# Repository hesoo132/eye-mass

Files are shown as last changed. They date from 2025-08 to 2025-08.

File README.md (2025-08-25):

# Eye-Mass Board  

## 🔎 Overview
**Eye-Mass** is a custom embedded hardware board designed for **real-time image processing and AI experimentation**.  
It integrates a camera (OV5640), external SDRAM, motor control, and communication interfaces to enable tasks such as **capturing and analyzing images of components inside a box**.

---

## 🔧 Hardware Features

| Component | Purpose |
|---|---|
| **Debug LED** | Visual feedback for board status and firmware debugging |
| **SDRAM** | Additional memory for buffering image data and running lightweight AI |
| **OV5640 Camera** | Captures images (e.g., counting SMD components inside a box) |
| **Motor Driver** | Moves the camera to capture the entire box view |
| **FDCAN** | High-speed, reliable communication with external modules |
| **USART** | Serial interface for debugging and logging |
| **Temperature Sensor**  | Monitors motor driver and board ambient temperature |
| **Current/Voltage Monitor** | Measures system power consumption and provides protection |

---

## 📸 Hardware Overview
| PCB Top | PCB Bottom |
|---|---|
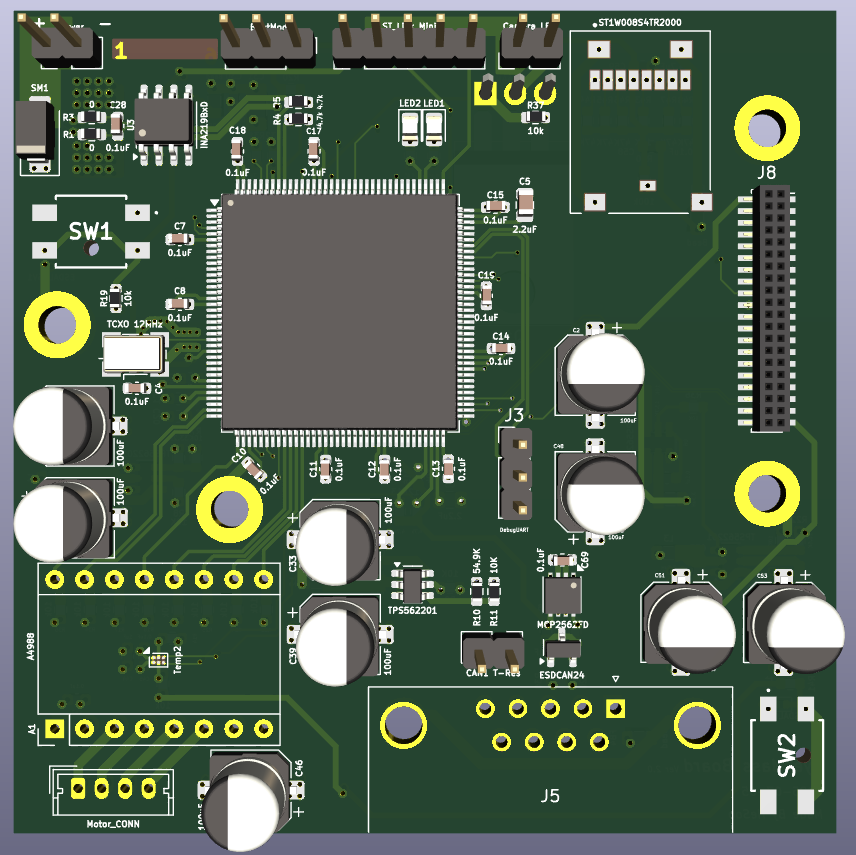
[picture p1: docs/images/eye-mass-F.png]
Top
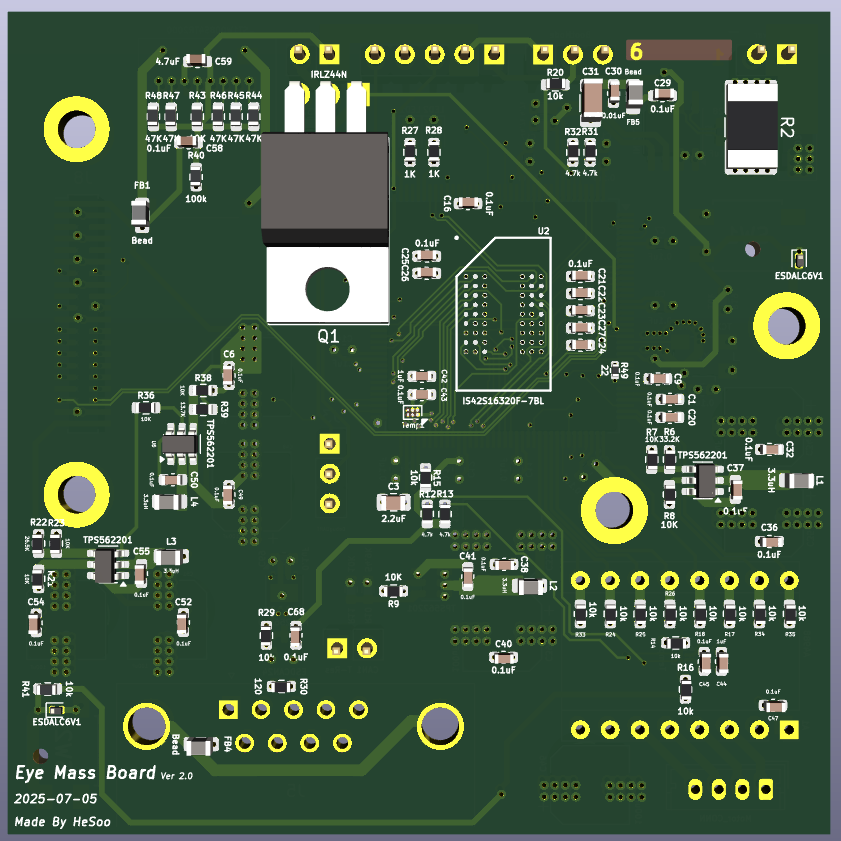
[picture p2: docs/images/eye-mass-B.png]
Bottom
|  |  |

---

## ✅ Current Status
- [x] Schematic design completed
- [x] PCB prototype (Rev. A) fabricated
- [x] SDRAM bring-up and validation
- [ ] Camera interface bring-up (OV5640)
- [x] Motor control & positioning test
- [x] Communication test (FDCAN, USART)
- [ ] Firmware integration (image capture + AI experimentation)

---

## 📑 References
- [STM32H7 Reference Manual](https://www.st.com/resource/en/reference_manual/dm00314099.pdf)  
- [OV5640 Camera Datasheet](https://www.arducam.com/downloads/datasheet/OV5640DS.pdf)

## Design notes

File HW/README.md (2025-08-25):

# Eye-Mass Hardware Design

## 🔎 Overview
The **Eye-Mass Board** is a custom embedded platform designed for **camera-based vision tasks and AI experimentation**.  
It integrates an OV5640 camera, external SDRAM, motor driver, and multiple debug/monitoring features.

---

## 📸 PCB Overview
| Top View | Bottom View |
|---|---|
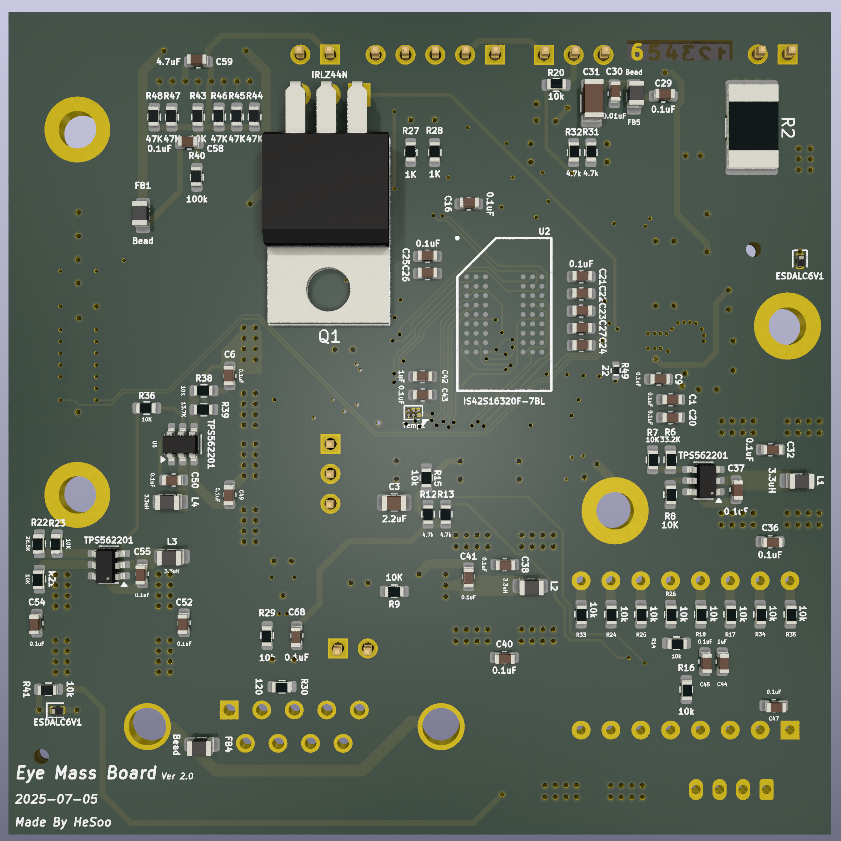
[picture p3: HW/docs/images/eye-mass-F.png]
Top
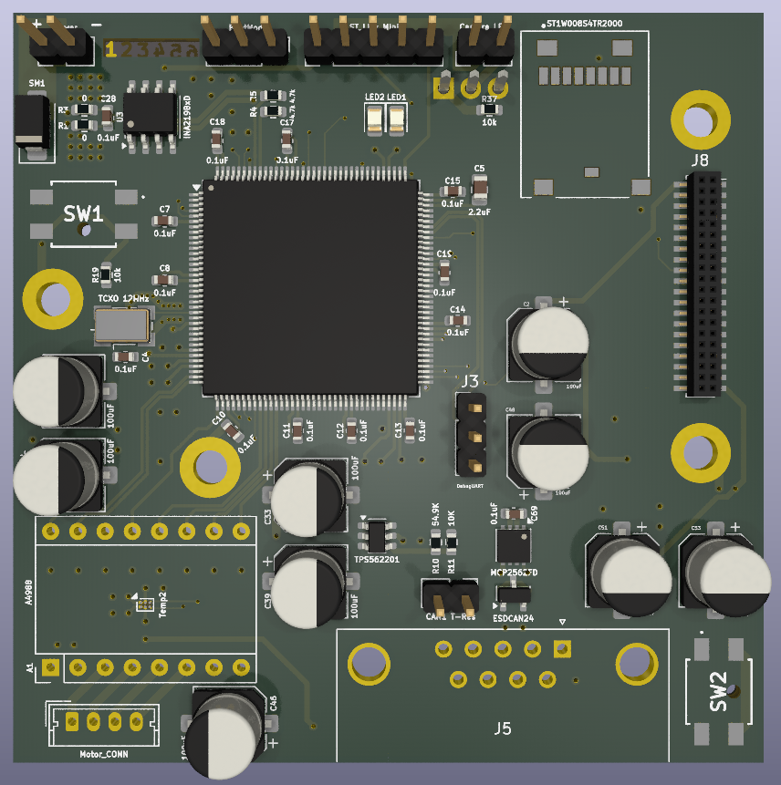
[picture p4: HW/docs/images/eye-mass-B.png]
Bottom
|  |  |

---

## 📑 Design Resources

- **Schematics**: [eye-mass.pdf](eye-mass.pdf) (PDF for quick view)
    
---

## 🔧 Key Hardware Notes
- **EDA Tool**: KiCad 9.0  
- **PCB Stackup**: 6-layer, impedance-controlled for high-speed (DCMI, FDCAN)  
- **Memory**: External SDRAM for real-time image buffering + AI workloads  
- **Camera**: OV5640 with DCMI interface for capturing and analysis  
- **Motor Driver**: Enables camera positioning to capture full target area  
- **Debugging**: LEDs + USART interface  
- **Monitoring**: Temperature and current/voltage sensing  

---

## 🧩 Schematic Highlights

### 1) MCU — STM32H723ZGT6
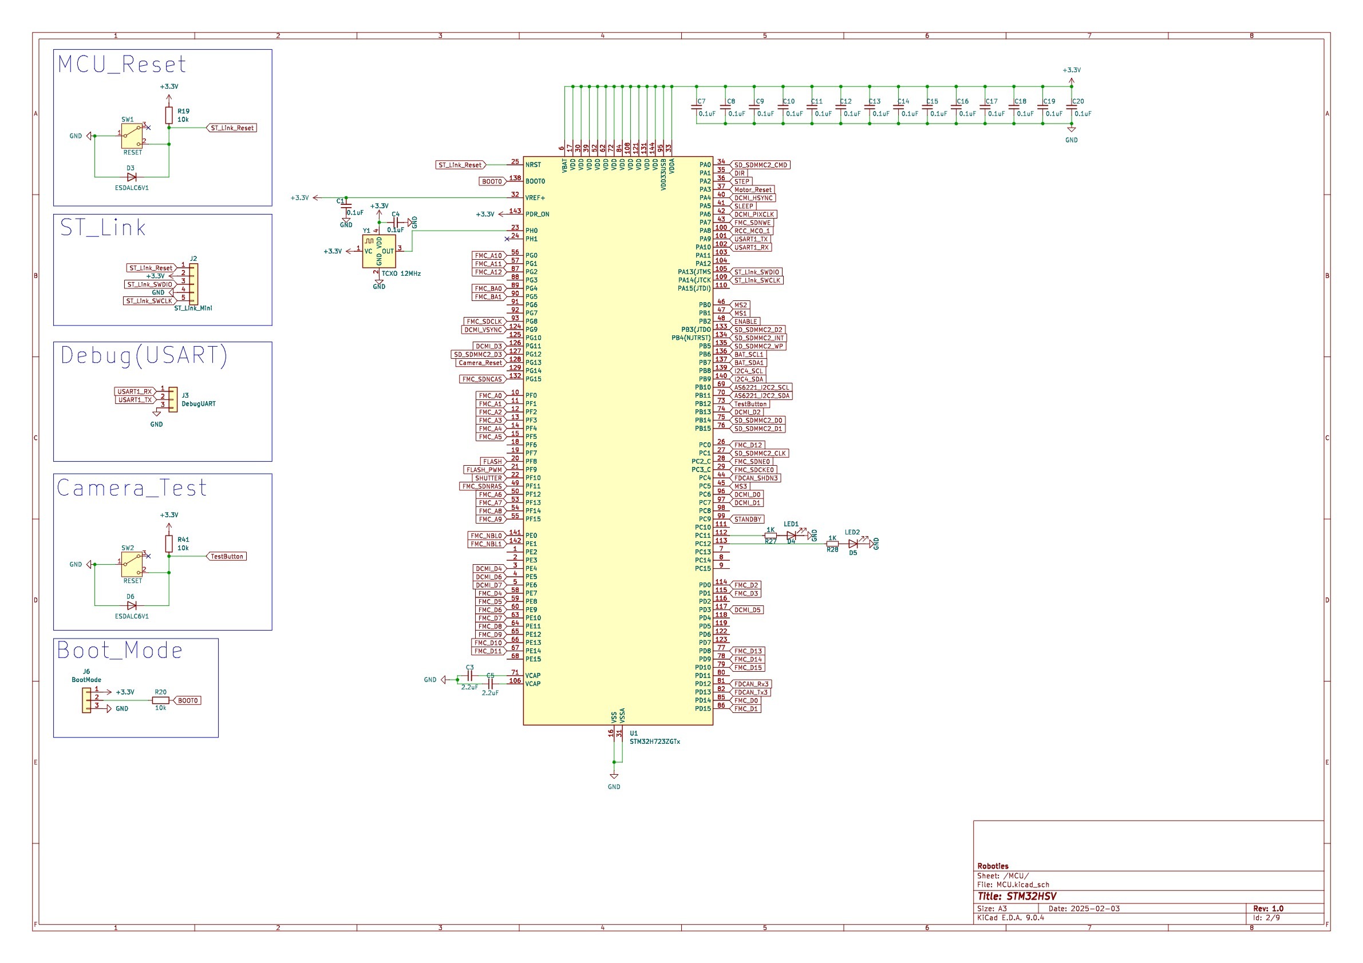
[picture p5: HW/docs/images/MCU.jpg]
MCU

- **Device**: STM32H723ZGT6 
- **Connections**: Debug UART, **ST-Link Mini** (SWD), boot-mode pins, GPIO banks **PA/PB/PC/PD/PE/PF/PG**, external clock **TCXO 12 MHz**, reset circuit  
- **Purpose**: Central control with dedicated debug/boot paths and ample I/O for peripherals

### 2) SDRAM — IS42S16320F-7BL
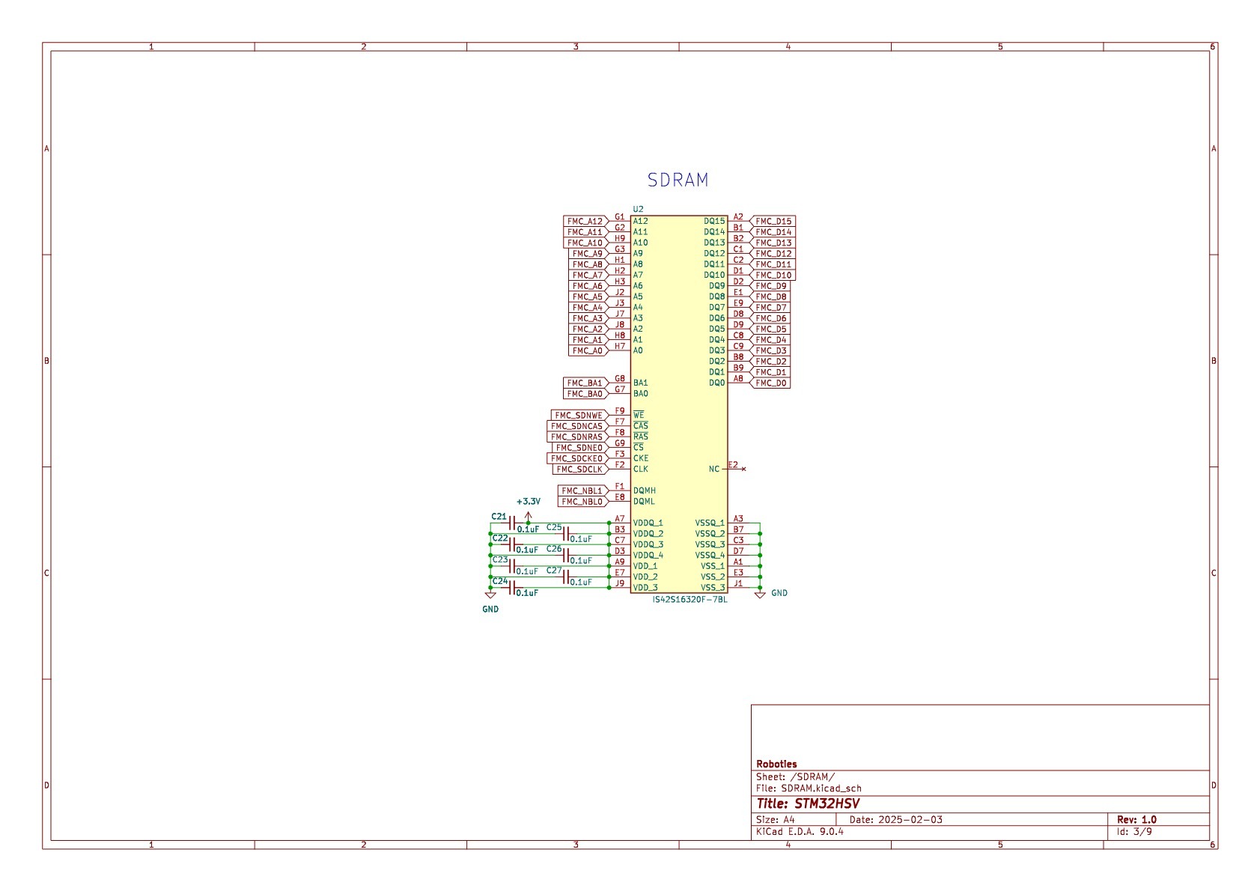
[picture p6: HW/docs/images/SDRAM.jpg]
SDRAM

- **Device**: IS42S16320F-7BL  
- **Interface**: **FMC** — DQ0–DQ15, A0–A12, BA0–BA1, **SDNWE/SDNCAS/SDNRAS/SDNE0/SDCKE0/SDCLK**, NBL0/NBL1  
- **Purpose**: External memory to expand capacity for image buffering and lightweight AI execution

### 3) Power
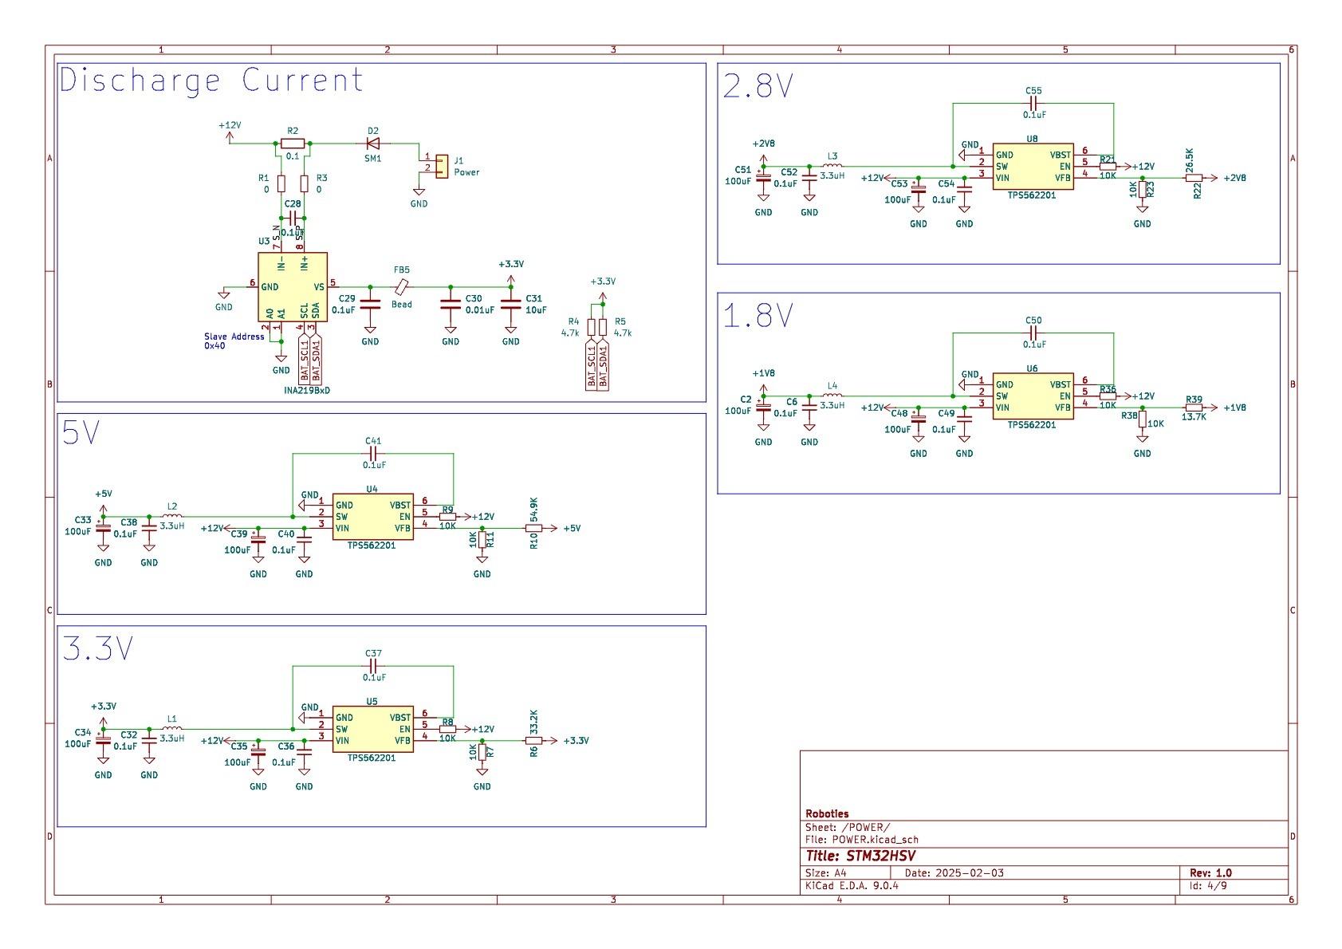
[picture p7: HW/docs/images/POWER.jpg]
Power

- **Key ICs**: **INA219BxD** (current/voltage monitor), **TPS562201** (buck converter)  
- **Rails**: From **+12 V** input to **+5 V / +3.3 V / +2.8 V / +1.8 V**  
- **Purpose**: Stable multi-rail supply with inline power telemetry for easier power management

### 4) Camera — OV5640
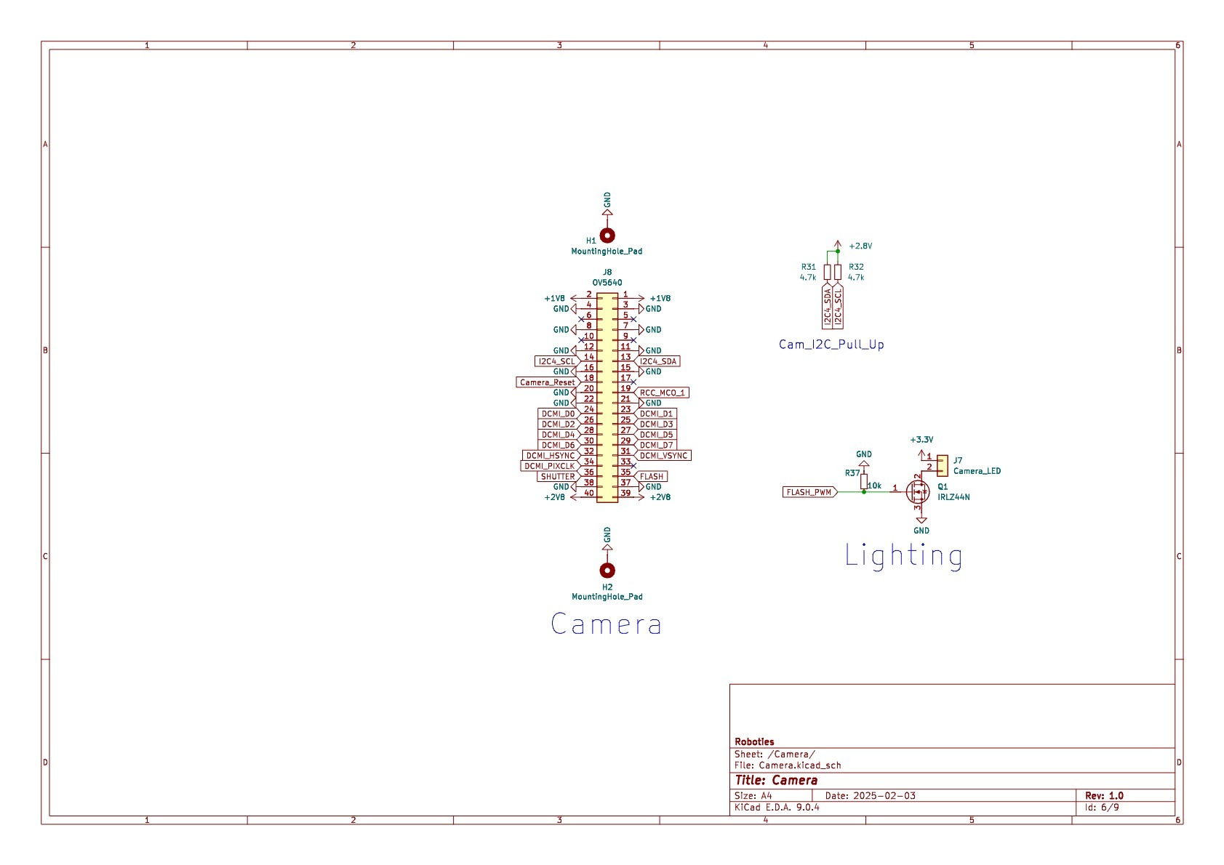
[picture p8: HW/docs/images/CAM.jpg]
Camera

- **Sensor**: **OV5640**  
- **Interface**: **DCMI** (D0–D7, HSYNC, VSYNC, PIXCLK) + **I²C4** (SCL, SDA)  
- **Power & Control**: **+1.8 V / +2.8 V / +3.3 V** rails, LED control (**Camera_LED**, **FLASH**, **FLASH_PWM**)  
- **Use Case**: Capturing images for tasks like **counting SMD components inside a box**

### 5) FDCAN
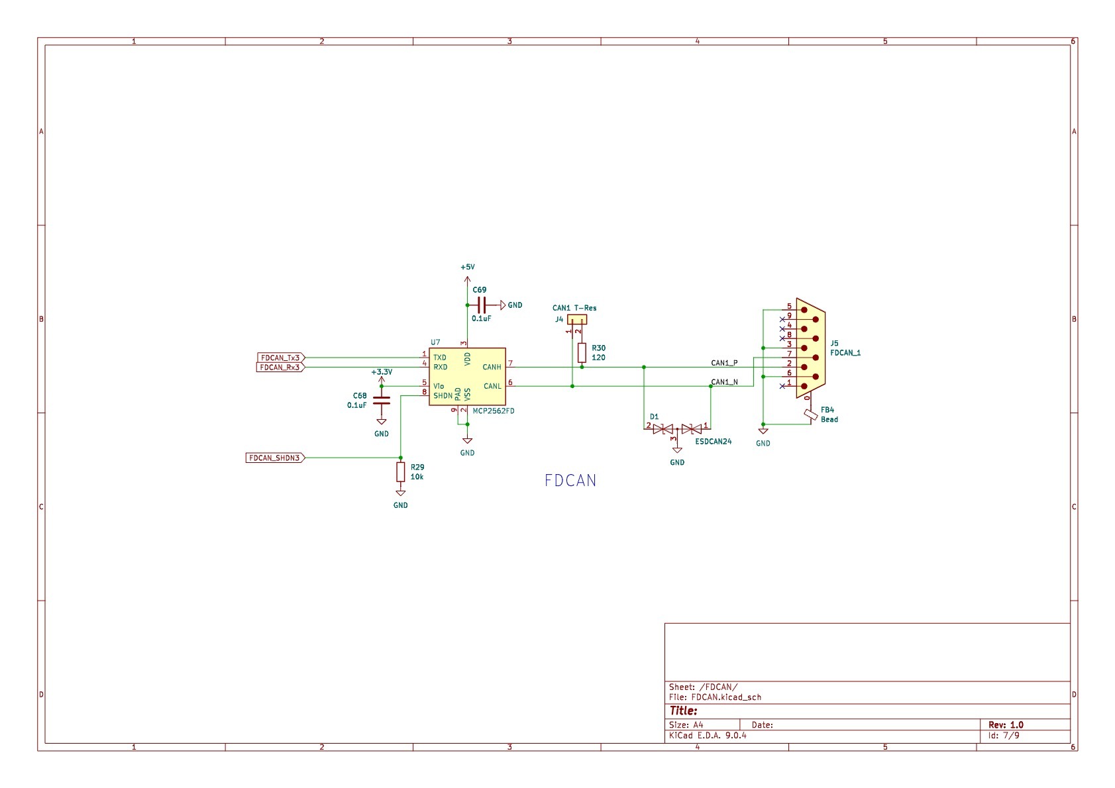
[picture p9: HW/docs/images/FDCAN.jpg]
FDCAN

- **Transceiver**: **MCP2562FD**  
- **Connections**: MCU **FDCAN_Tx3 / FDCAN_Rx3** ↔ bus **CANH/CANL**; includes **120 Ω** termination  
- **Purpose**: Robust CAN communication to external modules/systems

### 6) Temperature — AS6221 ×2
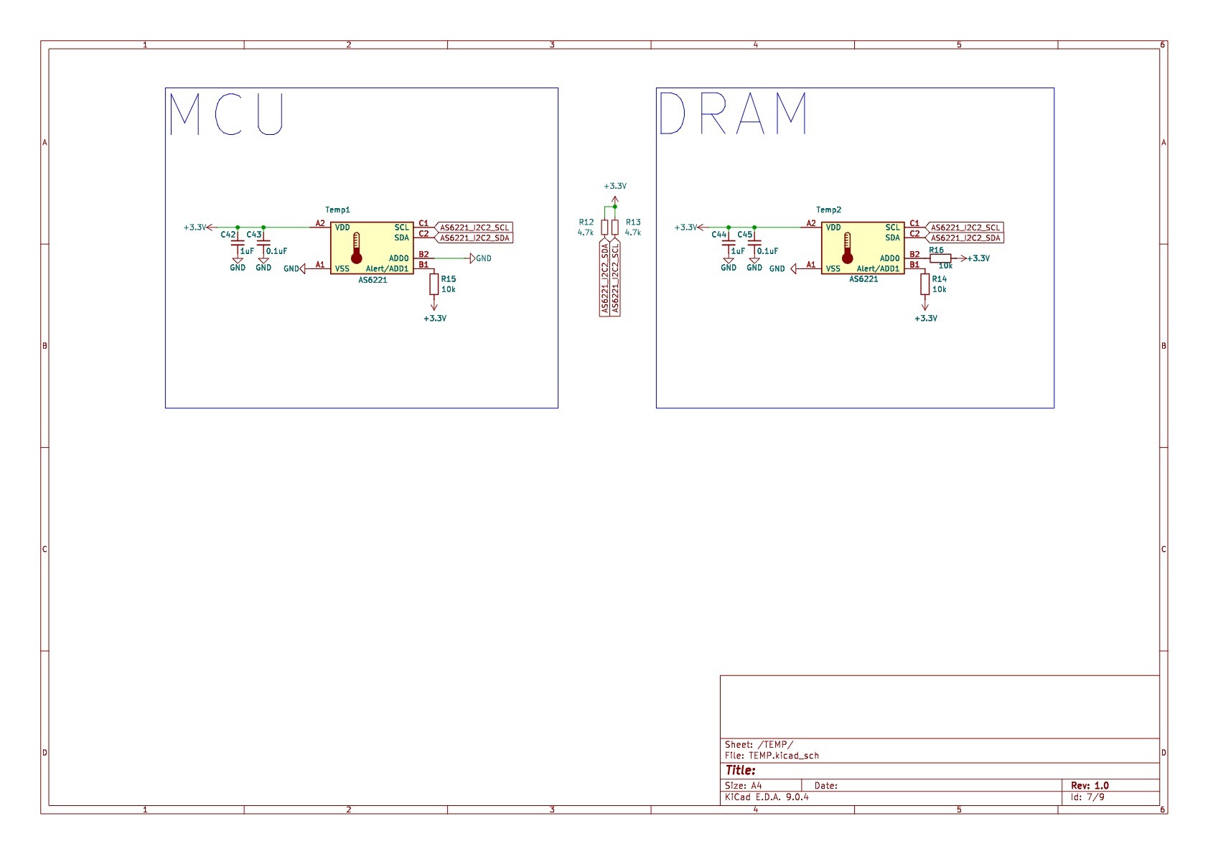
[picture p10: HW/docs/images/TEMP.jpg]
Temp

- **Sensors**: **AS6221** ×2  
- **Interface**: **I²C2** (SCL, SDA)  
- **Purpose**: Dual-point temperature monitoring (e.g., motor driver and board ambient)

### 7) Motor Driver — A4988
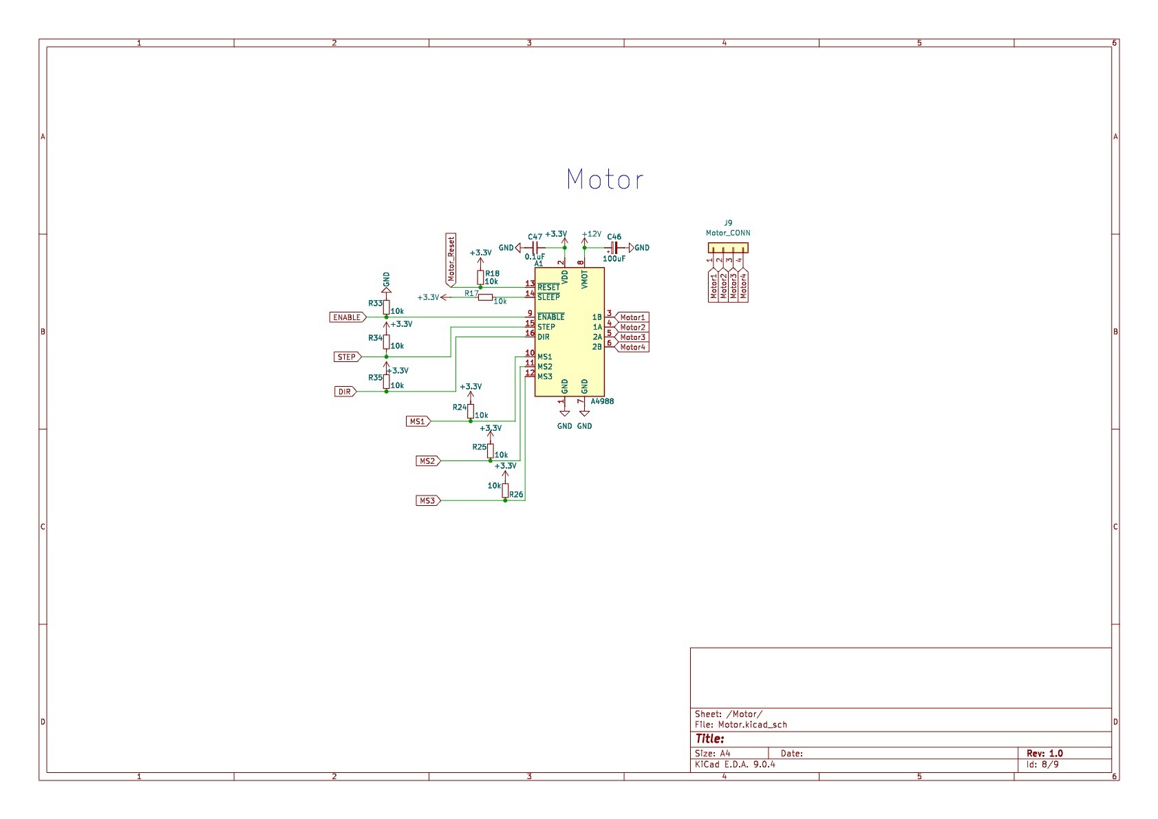
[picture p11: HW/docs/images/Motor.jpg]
Motor

- **Driver**: **A4988**  
- **Signals**: **STEP, DIR, ENABLE, MS1, MS2, MS3**; outputs **1A/1B/2A/2B**  
- **Purpose**: Stepper control with microstepping configuration for camera positioning

### 8) microSD — SDMMC2
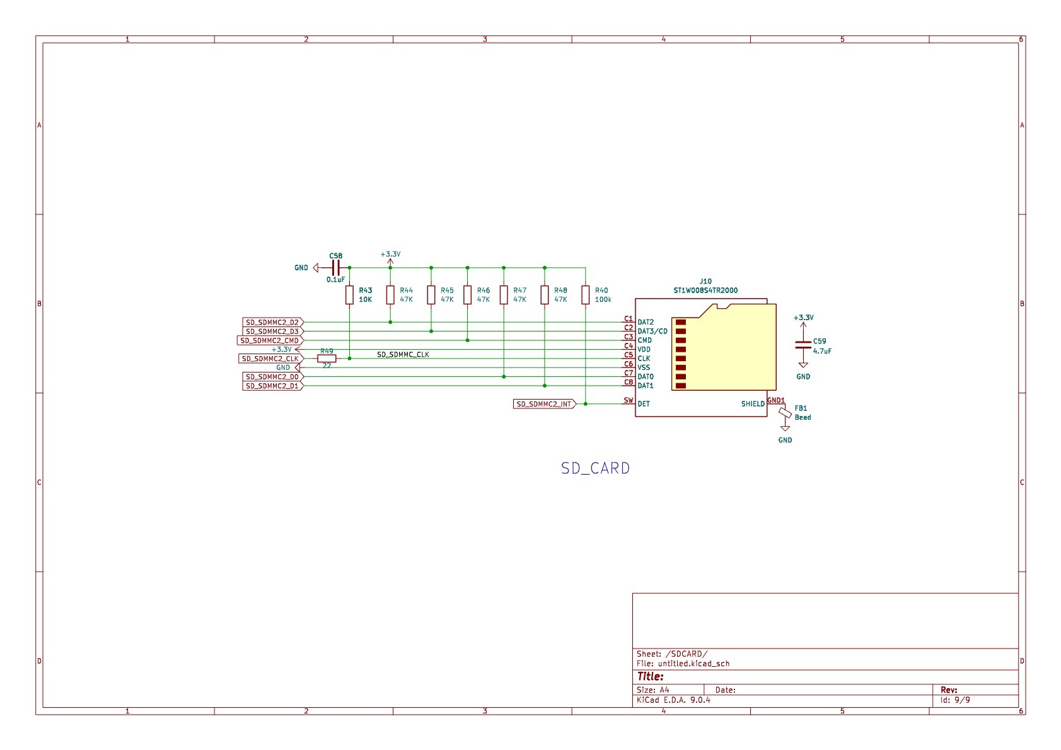
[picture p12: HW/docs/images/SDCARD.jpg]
SD

- **Interface**: **SDMMC2** — D0–D3, CMD, CLK, INT  
- **Purpose**: Removable storage for images and logs

---

## ✅ Progress
- [x] Schematics completed  
- [x] PCB prototype (Rev. A) fabricated  
- [x] SDRAM bring-up (partial validation ongoing)  
- [ ] Camera interface bring-up (OV5640)  
- [x] Motor driver test & positioning control  
- [x] Communication tests (FDCAN / USART)

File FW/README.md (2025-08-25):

# 📷 STM32H723ZGT6 – Vision & Control Firmware

## 🔎 Overview
This firmware is developed for the **STM32H723ZGT6** based embedded platform.  
The system is designed to capture images of **SMD components inside a box** and perform counting with camera + AI (WIP).  
It integrates **external SDRAM, motor driver, SD card logging, temperature/current sensors, and FDCAN communication**.

---

## ⚙️ Features

- ✅ **SD Card (SDMMC2)**  
  - File creation & logging tested successfully  
  - Stores captured data and sensor logs

- ✅ **SDRAM (IS42S16320F-6BLI)**  
  - JEDEC init sequence implemented  
  - Full memory write/read test completed

- ✅ **Motor Control (A4988)**  
  - Supports speed & distance control  
  - Verified positioning logic for camera movement

- ✅ **Temperature Sensor (AS6221)**  
  - I²C2 interface  
  - Accurate ambient + board temp reading

- ✅ **Current/Voltage Monitor (INA219B)**  
  - I²C3 interface  
  - Real-time bus voltage & shunt current measurement

- ✅ **FDCAN Communication**  
  - I²C4 interface 
  - Protocol layer implemented  
  - Verified with external CAN nodes

- ⏳ **Camera (OV5640 + DCMI DMA)**  
  - Basic bring-up in progress  
  - SDRAM frame buffer prepared  
  - AI-based SMD counting pipeline: **Planned**

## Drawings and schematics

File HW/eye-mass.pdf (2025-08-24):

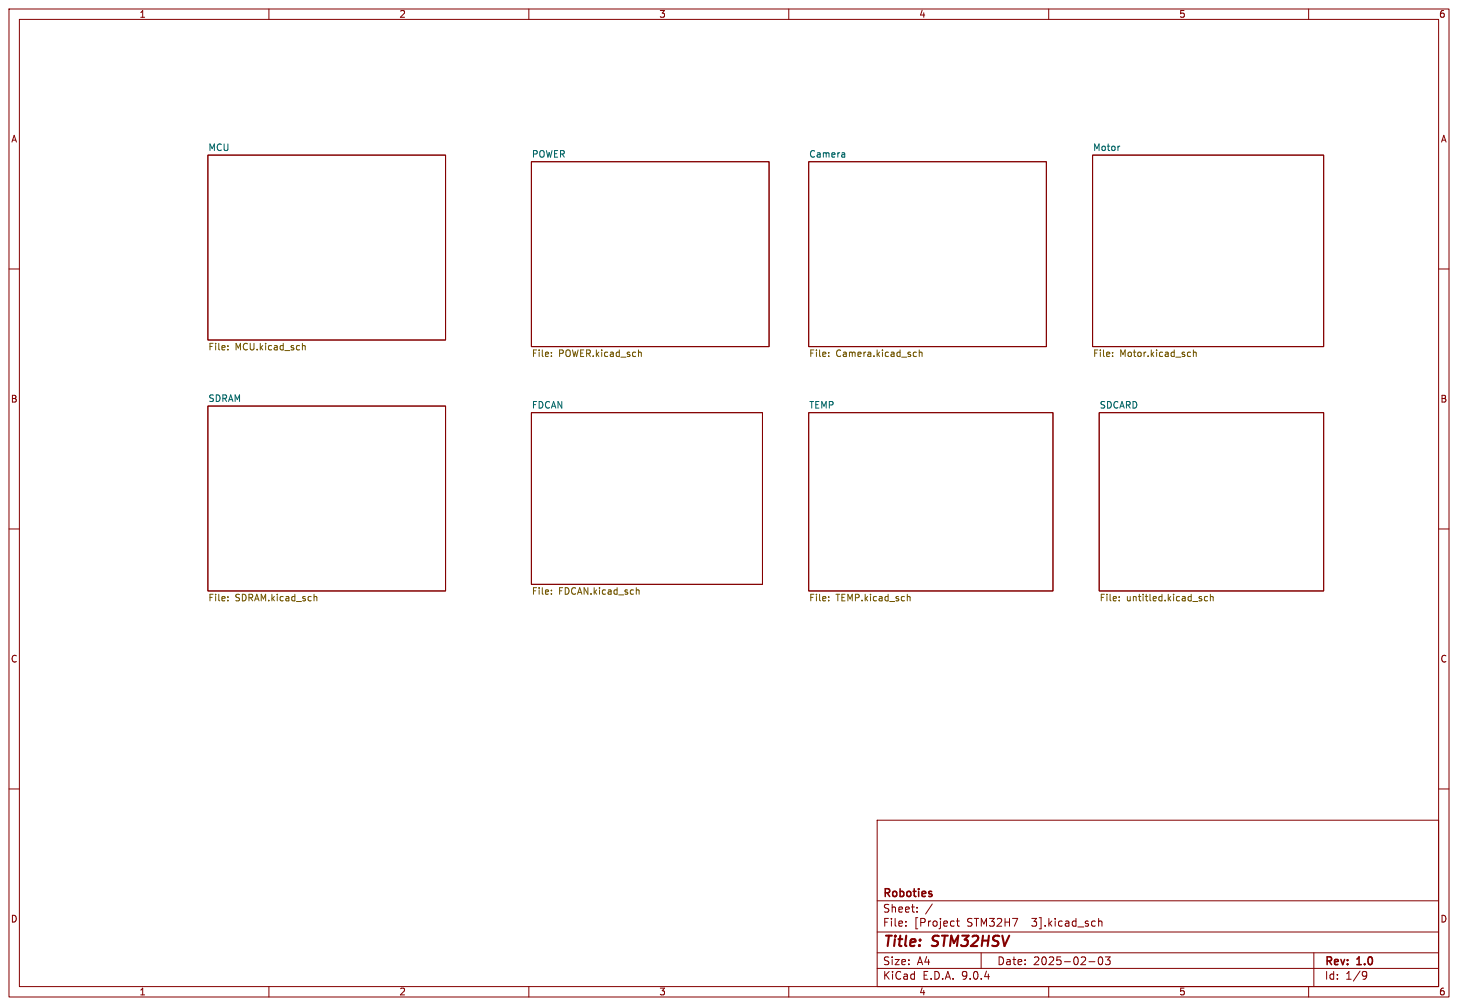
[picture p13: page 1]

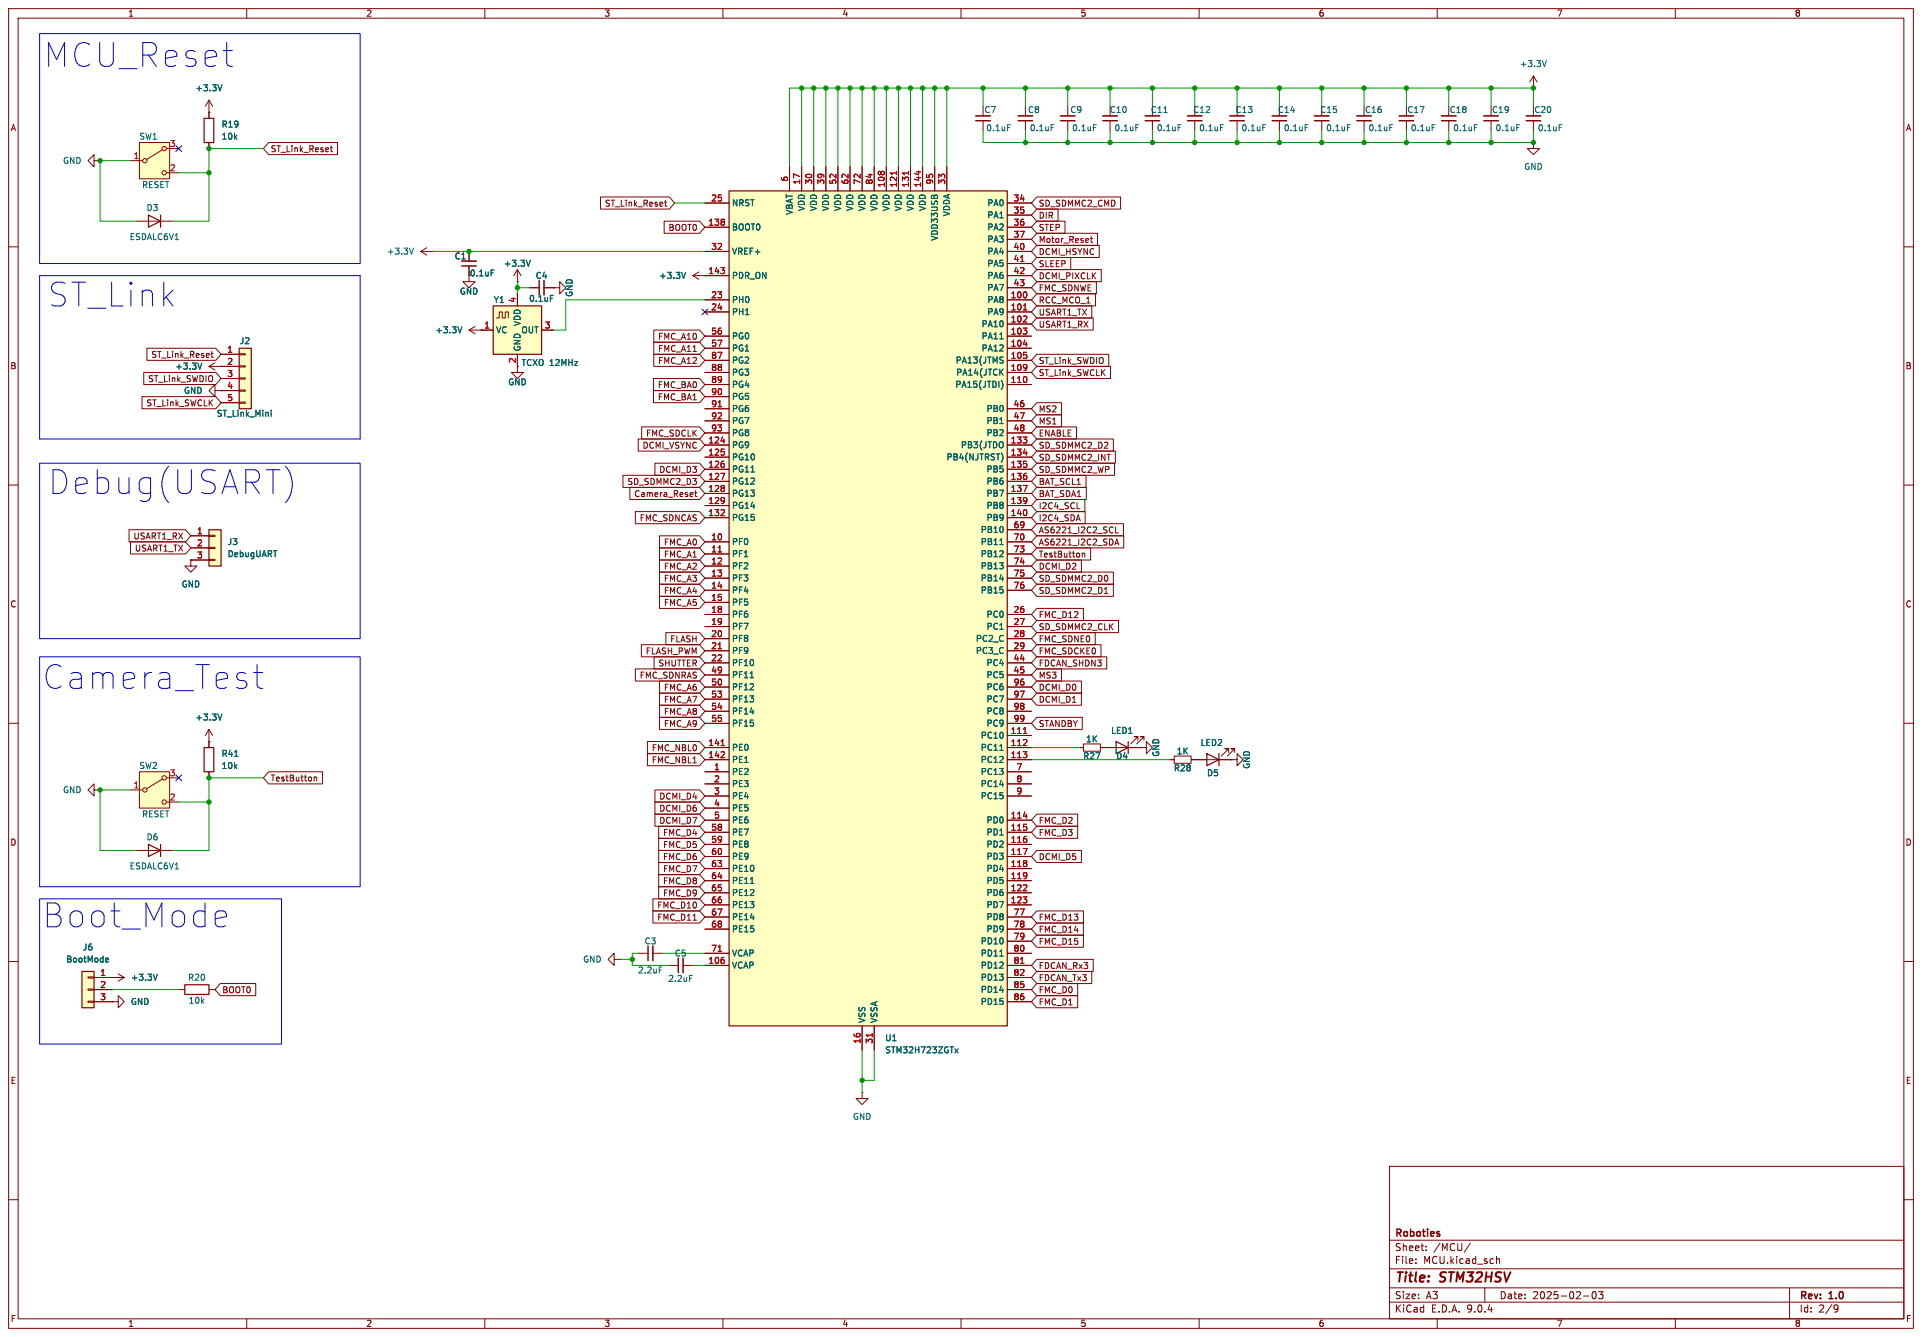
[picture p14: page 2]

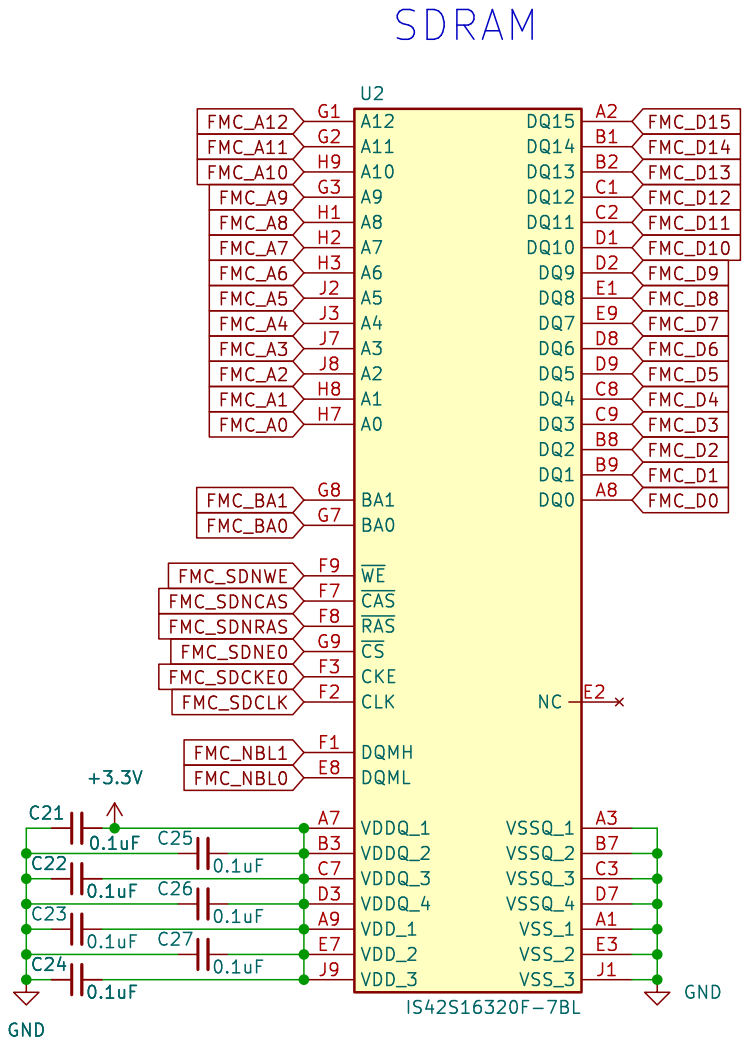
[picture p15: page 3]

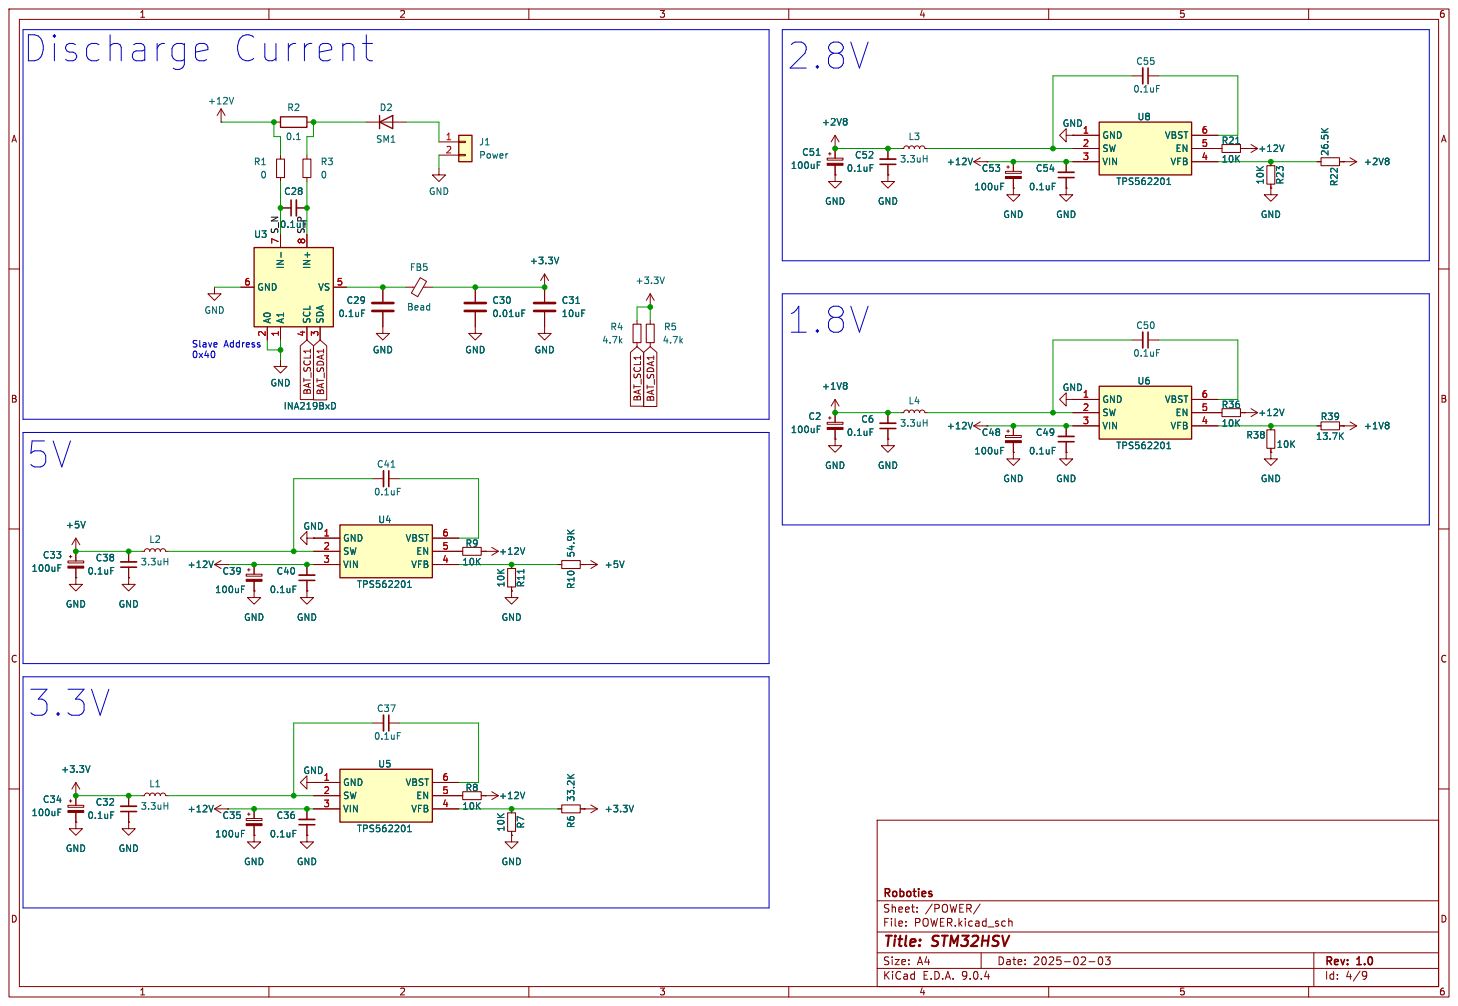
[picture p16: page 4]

8 IN- 7 VS 5 GND 6 SDA

File: POWER.kicad_sch Sheet: /POWER/ Roboties C40

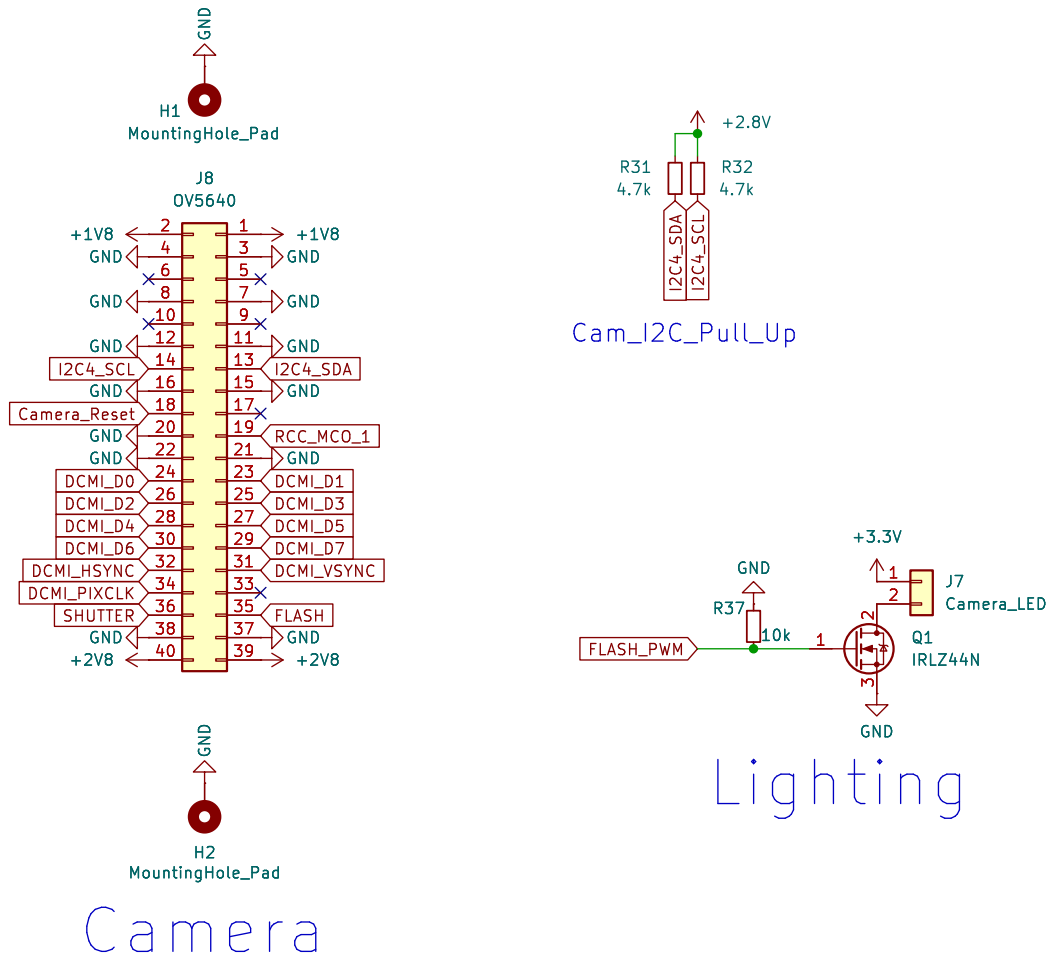
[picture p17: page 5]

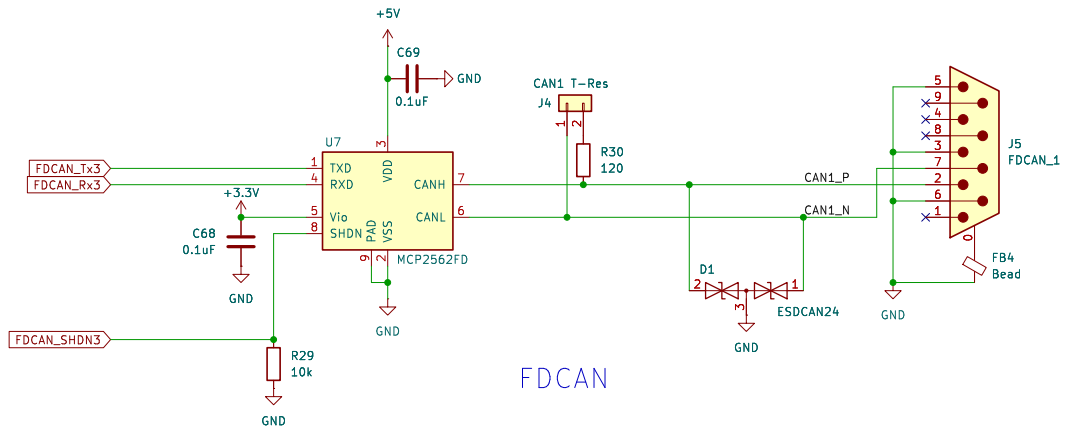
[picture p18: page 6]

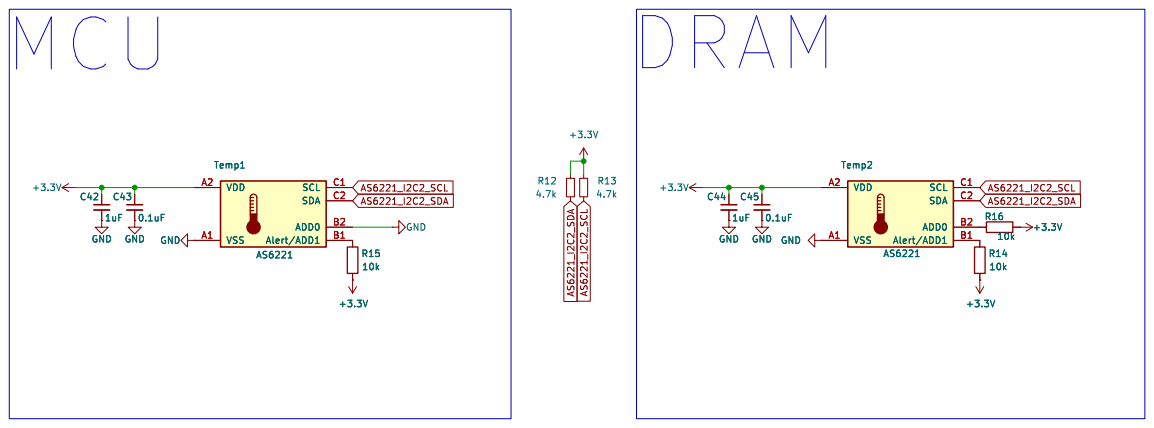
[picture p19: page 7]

Id: 7/9 Title: File: TEMP.kicad_sch Sheet: /TEMP/

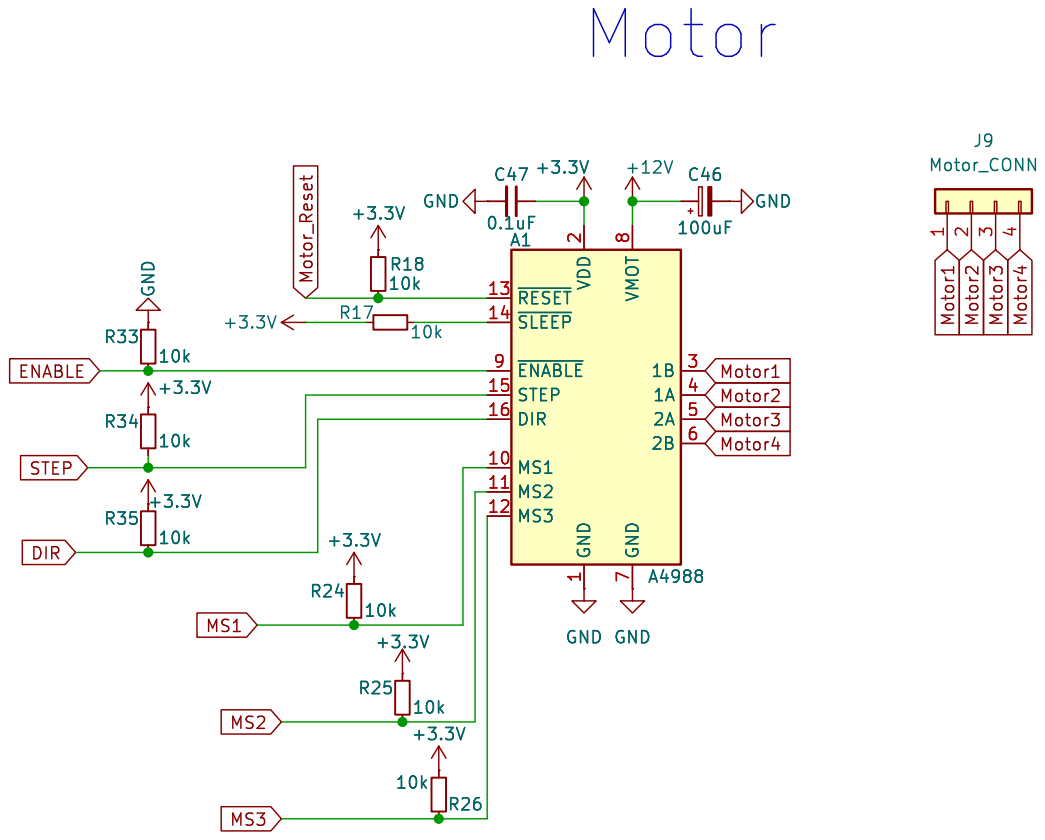
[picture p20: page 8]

Id: 8/9 Title: File: Motor.kicad_sch Sheet: /Motor/

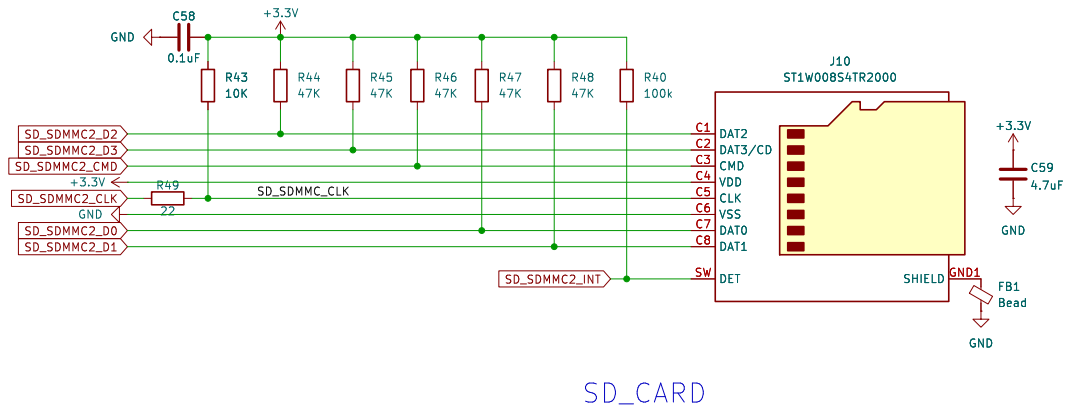
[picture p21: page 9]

Id: 9/9 Title: File: untitled.kicad_sch Sheet: /SDCARD/

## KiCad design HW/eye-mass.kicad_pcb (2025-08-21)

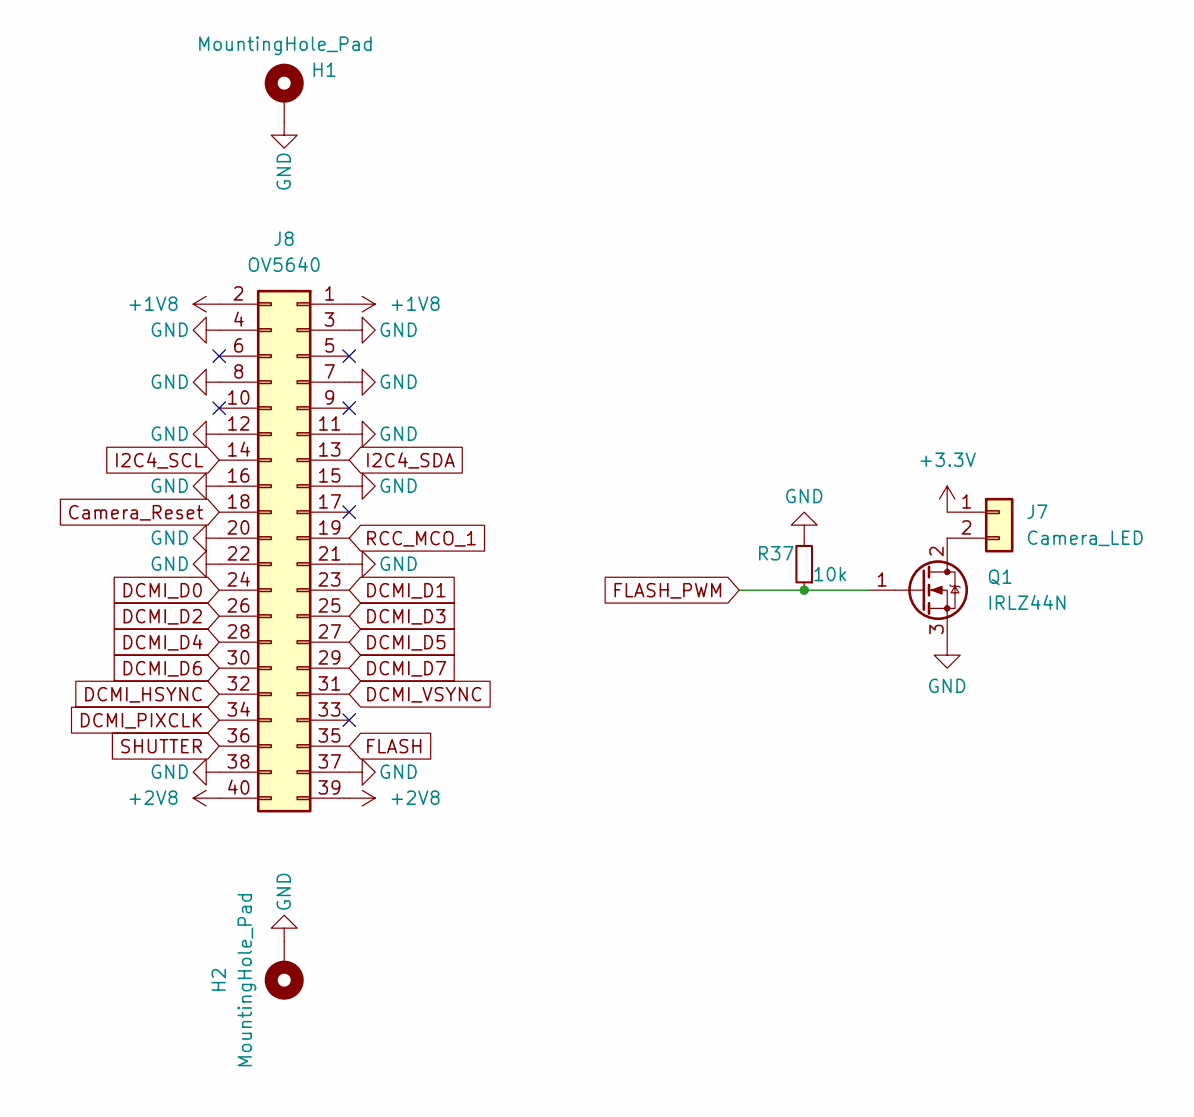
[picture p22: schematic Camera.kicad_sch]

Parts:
H1, H2: MountingHole_Pad; MountingHole_3.2mm_M3_DIN965_Pad
J7: Camera_LED; PinHeader_1x02_P2.54mm_Vertical
J8: OV5640; PinSocket_2x20_P1.00mm_Vertical_SMD
Q1: IRLZ44N; TO-220-3_Horizontal_TabDown
R37: 10k; R_0603_1608Metric

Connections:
+1V8: J8.1, J8.2; also elsewhere on the board
+2V8: J8.39, J8.40; also elsewhere on the board
+3.3V: J7.1; also elsewhere on the board
Camera_Reset: J8.18; also elsewhere on the board
DCMI_D0: J8.24; also elsewhere on the board
DCMI_D1: J8.23; also elsewhere on the board
DCMI_D2: J8.26; also elsewhere on the board
DCMI_D3: J8.25; also elsewhere on the board
DCMI_D4: J8.28; also elsewhere on the board
DCMI_D5: J8.27; also elsewhere on the board
DCMI_D6: J8.30; also elsewhere on the board
DCMI_D7: J8.29; also elsewhere on the board
DCMI_HSYNC: J8.32; also elsewhere on the board
DCMI_PIXCLK: J8.34; also elsewhere on the board
DCMI_VSYNC: J8.31; also elsewhere on the board
FLASH: J8.35; also elsewhere on the board
FLASH_PWM: Q1.1 (G), R37.1; also elsewhere on the board
GND: H1.1, H2.1, J8.3, J8.4, J8.7, J8.8, J8.11, J8.12, J8.15, J8.16, J8.20, J8.21, J8.22, J8.37, J8.38, Q1.3 (S), R37.2; also elsewhere on the board
I2C4_SCL: J8.14; also elsewhere on the board
I2C4_SDA: J8.13; also elsewhere on the board
unnamed: J7.2, Q1.2 (D)
RCC_MCO_1: J8.19; also elsewhere on the board
SHUTTER: J8.36; also elsewhere on the board

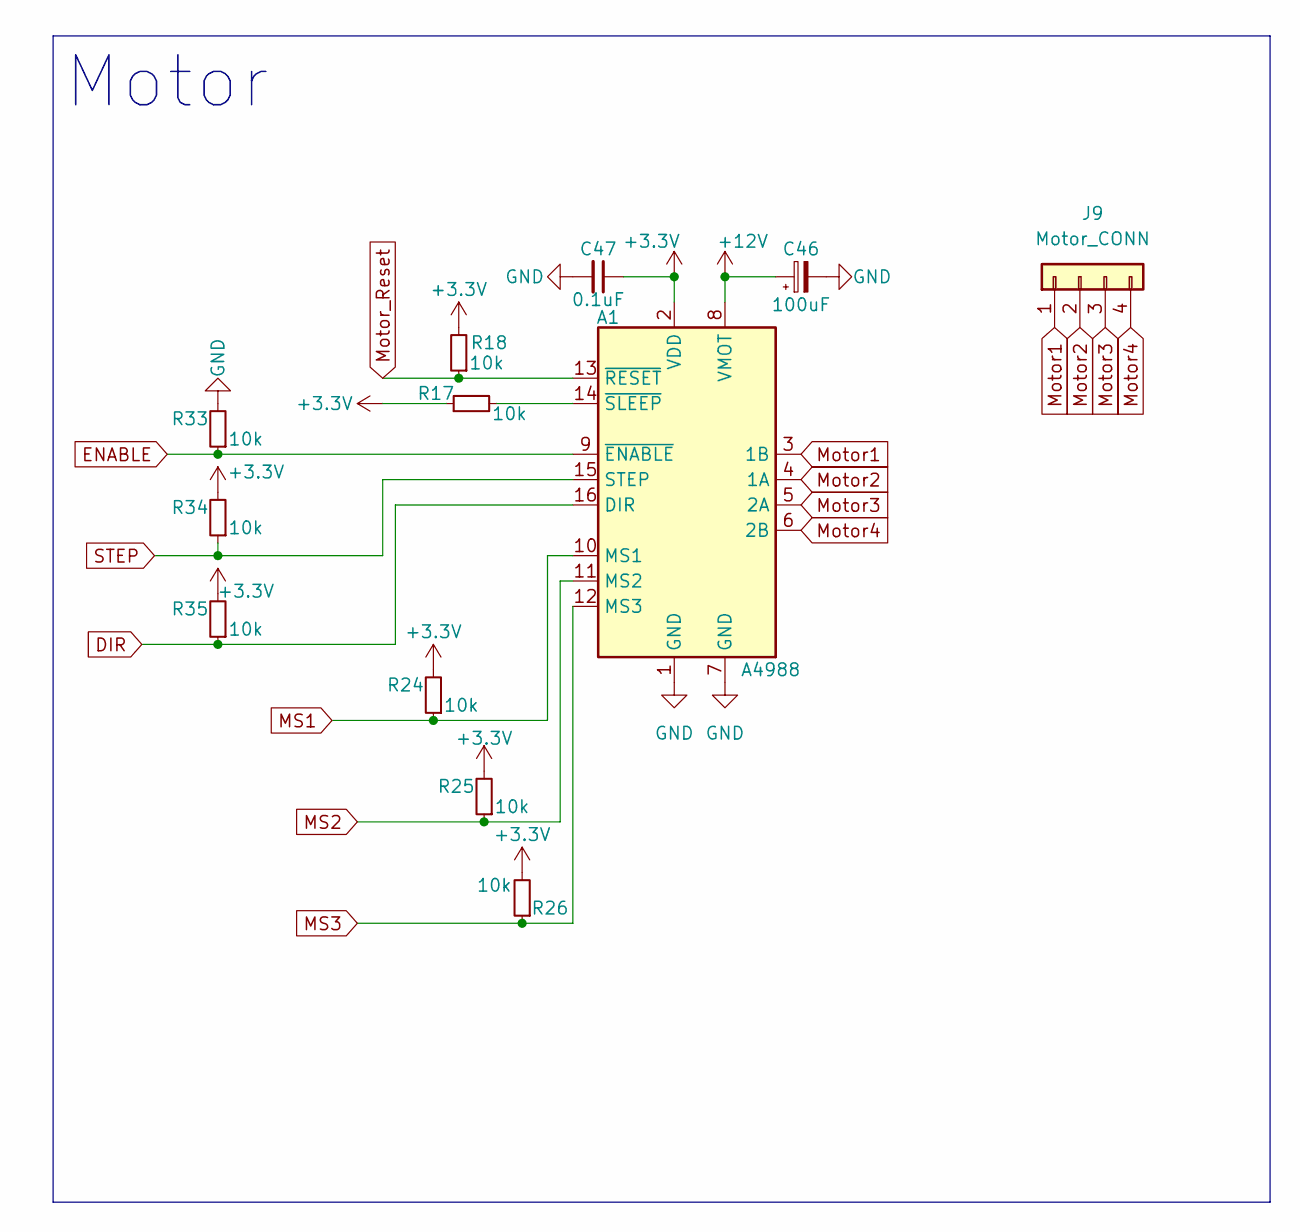
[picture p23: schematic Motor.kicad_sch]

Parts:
A1: A4988; Pololu_Breakout-16_15.2x20.3mm
C46: 100uF; CP_Elec_6.3x5.9
C47: 0.1uF; C_0603_1608Metric
J9: Motor_CONN; Molex_Micro-Latch_53253-0470_1x04_P2.00mm_Vertical
R17, R18, R24, R25, R26, R33, R34, R35: 10k; R_0603_1608Metric

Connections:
+3.3V: A1.2 (VDD), C47.1, R17.1, R18.2, R24.2, R25.2, R26.2, R34.2, R35.2; also elsewhere on the board
+12V: A1.8 (VMOT), C46.1; also elsewhere on the board
DIR: A1.16 (DIR), R35.1; also elsewhere on the board
ENABLE: A1.9 (~ENABLE), R33.1; also elsewhere on the board
GND: A1.1 (GND), A1.7 (GND), C46.2, C47.2, R33.2; also elsewhere on the board
MS1: A1.10 (MS1), R24.1; also elsewhere on the board
MS2: A1.11 (MS2), R25.1; also elsewhere on the board
MS3: A1.12 (MS3), R26.1; also elsewhere on the board
Motor1: A1.3 (1B), J9.1
Motor2: A1.4 (1A), J9.2
Motor3: A1.5 (2A), J9.3
Motor4: A1.6 (2B), J9.4
Motor_Reset: A1.13 (~RESET), R18.1; also elsewhere on the board
unnamed: A1.14 (~SLEEP), R17.2
STEP: A1.15 (STEP), R34.1; also elsewhere on the board

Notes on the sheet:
Motor

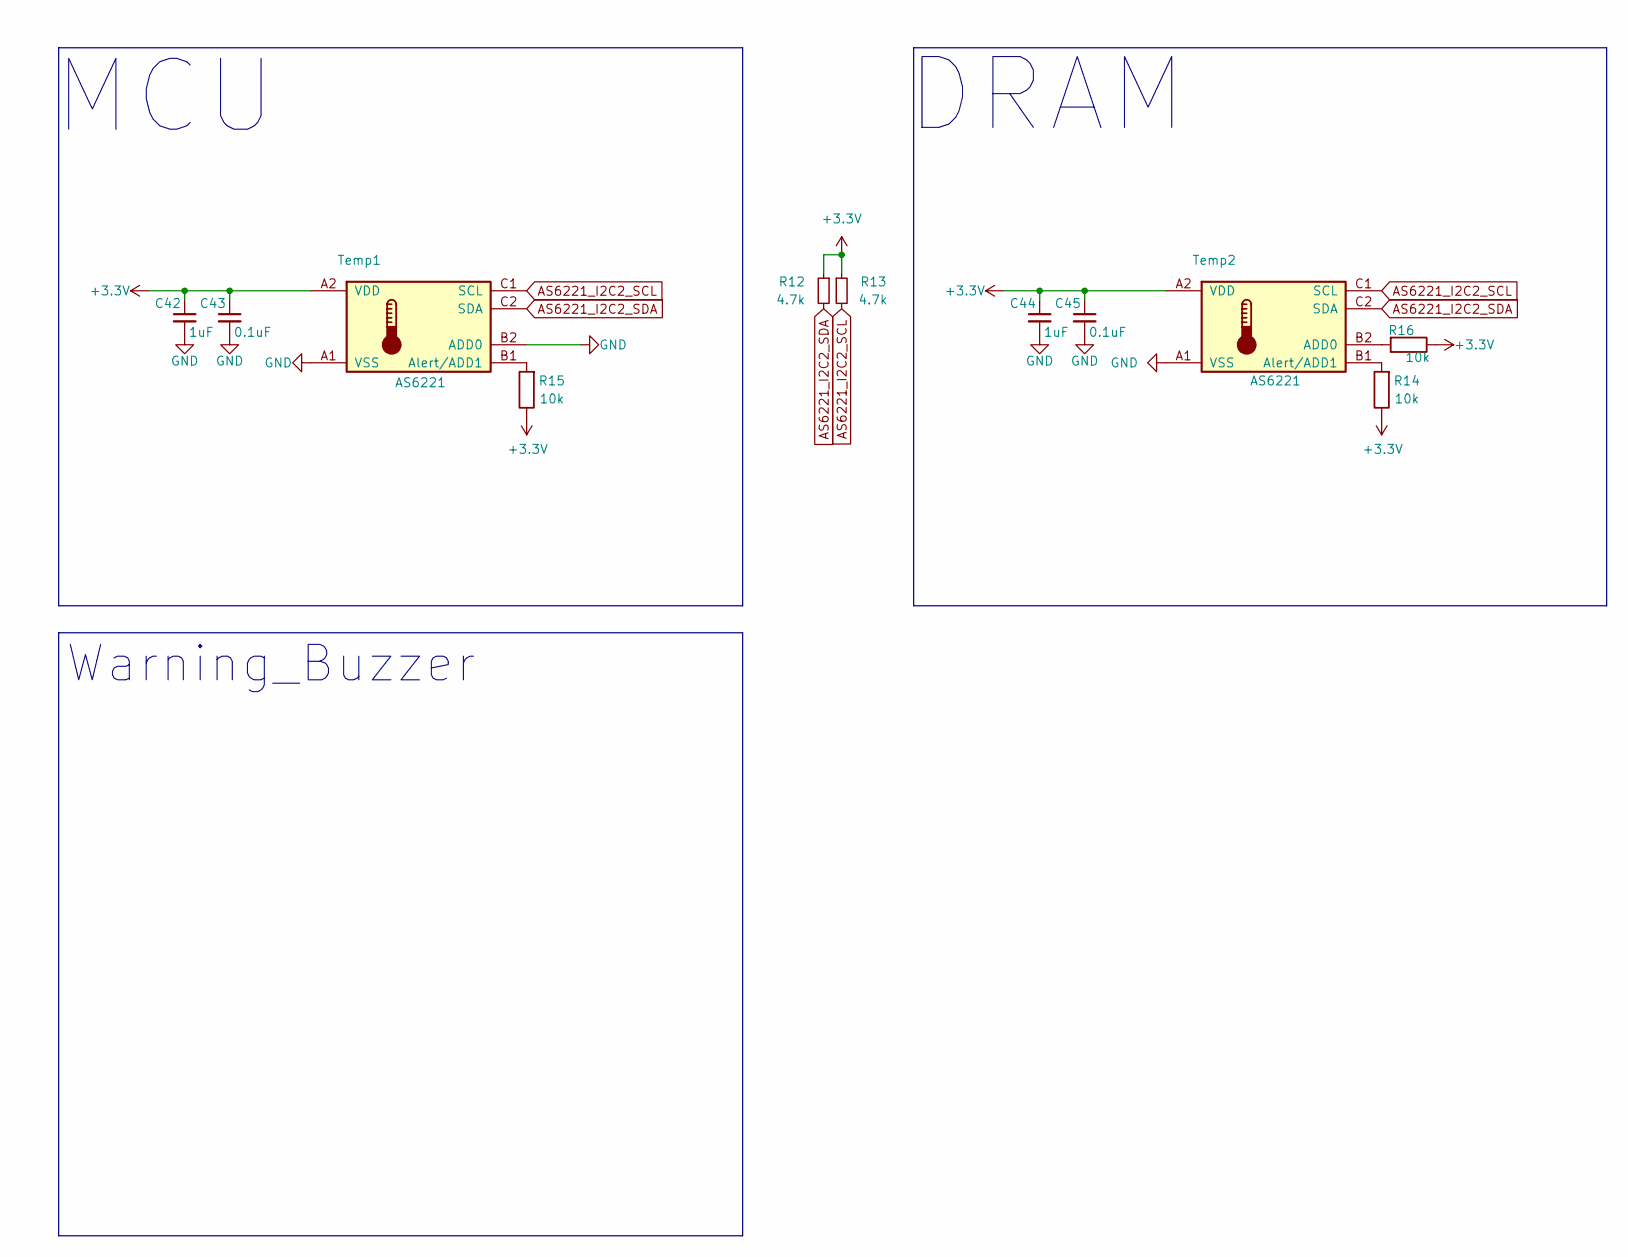
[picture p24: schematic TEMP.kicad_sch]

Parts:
C42, C44: 1uF; C_0603_1608Metric
C43, C45: 0.1uF; C_0603_1608Metric
R12, R13: 4.7k; R_0603_1608Metric
R14, R15, R16: 10k; R_0603_1608Metric
Temp1, Temp2: AS6221; WLCSP-6_1.4x1.0mm_P0.4mm

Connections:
+3.3V: C42.1, C43.1, C44.1, C45.1, R12.1, R13.1, R14.1, R15.1, R16.1, Temp1.A2 (VDD), Temp2.A2 (VDD); also elsewhere on the board
AS6221_I2C2_SCL: R13.2, Temp1.C1 (SCL), Temp2.C1 (SCL); also elsewhere on the board
AS6221_I2C2_SDA: R12.2, Temp1.C2 (SDA), Temp2.C2 (SDA); also elsewhere on the board
GND: C42.2, C43.2, C44.2, C45.2, Temp1.A1 (VSS), Temp1.B2 (ADD0), Temp2.A1 (VSS); also elsewhere on the board
unnamed: R15.2, Temp1.B1 (Alert/ADD1)
unnamed: R16.2, Temp2.B2 (ADD0)
unnamed: R14.2, Temp2.B1 (Alert/ADD1)

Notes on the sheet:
Warning_Buzzer
MCU
DRAM

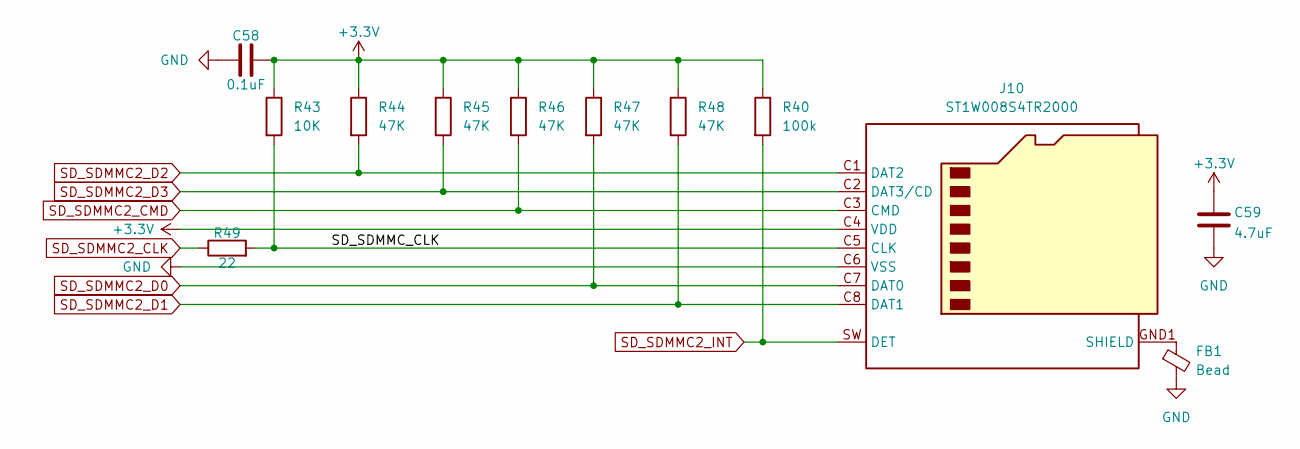
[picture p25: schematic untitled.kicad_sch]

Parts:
C58: 0.1uF; C_0603_1608Metric
C59: 4.7uF; C_0603_1608Metric
FB1: Bead; L_0805_2012Metric
J10: ST1W008S4TR2000; JAE_ST1W008S4TR2000
R40: 100k; R_0603_1608Metric
R43: 10K; R_0603_1608Metric
R44, R45, R46, R47, R48: 47K; R_0603_1608Metric
R49: 22; R_0402_1005Metric

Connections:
+3.3V: C58.2, C59.2, J10.C4 (VDD), R40.1, R43.1, R44.1, R45.1, R46.1, R47.1, R48.1; also elsewhere on the board
/SDCARD/SD_SDMMC_CLK: J10.C5 (CLK), R43.2, R49.2
GND: C58.1, C59.1, FB1.2, J10.C6 (VSS); also elsewhere on the board
unnamed: FB1.1, J10.GND1 (SHIELD), J10.GND2 (SHIELD), J10.GND3 (SHIELD), J10.GND4 (SHIELD)
SD_SDMMC2_CLK: R49.1; also elsewhere on the board
SD_SDMMC2_CMD: J10.C3 (CMD), R46.2; also elsewhere on the board
SD_SDMMC2_D0: J10.C7 (DAT0), R47.2; also elsewhere on the board
SD_SDMMC2_D1: J10.C8 (DAT1), R48.2; also elsewhere on the board
SD_SDMMC2_D2: J10.C1 (DAT2), R44.2; also elsewhere on the board
SD_SDMMC2_D3: J10.C2 (DAT3/CD), R45.2; also elsewhere on the board
SD_SDMMC2_INT: J10.SW (DET), R40.2; also elsewhere on the board

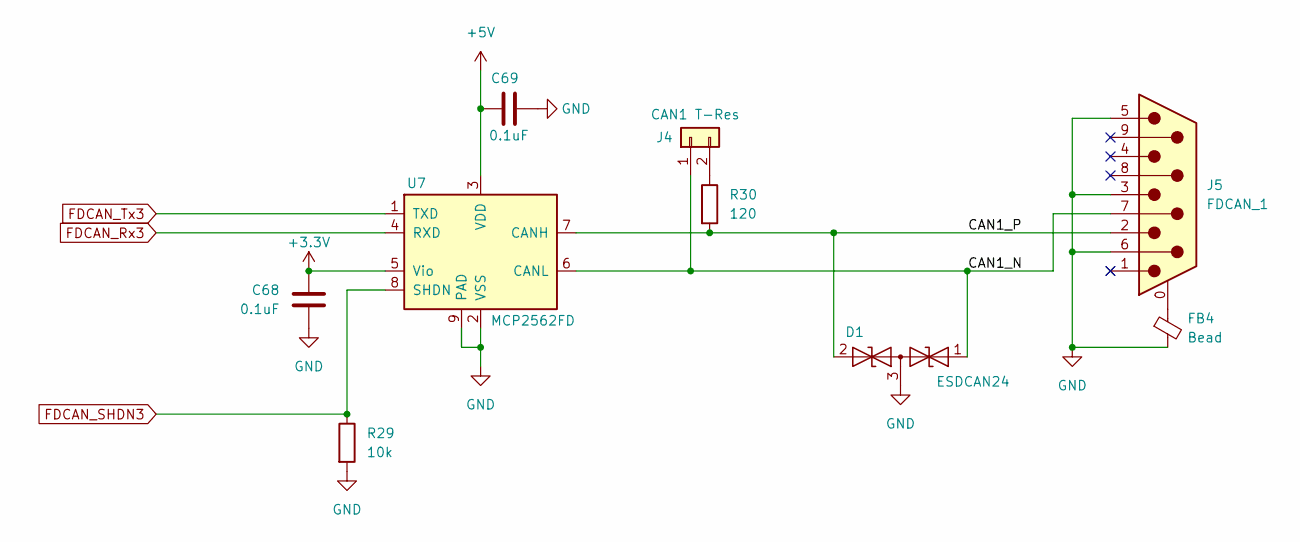
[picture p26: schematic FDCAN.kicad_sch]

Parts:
C68, C69: 0.1uF; C_0603_1608Metric
D1: ESDCAN24; SOT-23
FB4: Bead; L_0805_2012Metric
J4: CAN1 T-Res; PinHeader_1x02_P2.54mm_Vertical
J5: FDCAN_1; DSUB-9_Female_Horizontal_P2.77x2.84mm_EdgePinOffset7.70mm_H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
R29: 10k; R_0603_1608Metric
R30: 120; R_0603_1608Metric
U7: MCP2562FD; DFN-8-1EP_3x3mm_P0.65mm_EP1.55x2.4mm

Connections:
+3.3V: C68.1, U7.5 (Vio); also elsewhere on the board
+5V: C69.1, U7.3 (VDD); also elsewhere on the board
/FDCAN/CAN1_N: D1.1 (A1), J4.1, J5.7, U7.6 (CANL)
/FDCAN/CAN1_P: D1.2 (A2), J5.2, R30.2, U7.7 (CANH)
FDCAN_Rx3: U7.4 (RXD); also elsewhere on the board
FDCAN_SHDN3: R29.1, U7.8 (SHDN); also elsewhere on the board
FDCAN_Tx3: U7.1 (TXD); also elsewhere on the board
GND: C68.2, C69.2, D1.3 (common), FB4.2, J5.3, J5.5, J5.6, R29.2, U7.2 (VSS), U7.9 (PAD); also elsewhere on the board
unnamed: J4.2, R30.1
unnamed: FB4.1, J5.0 (PAD)

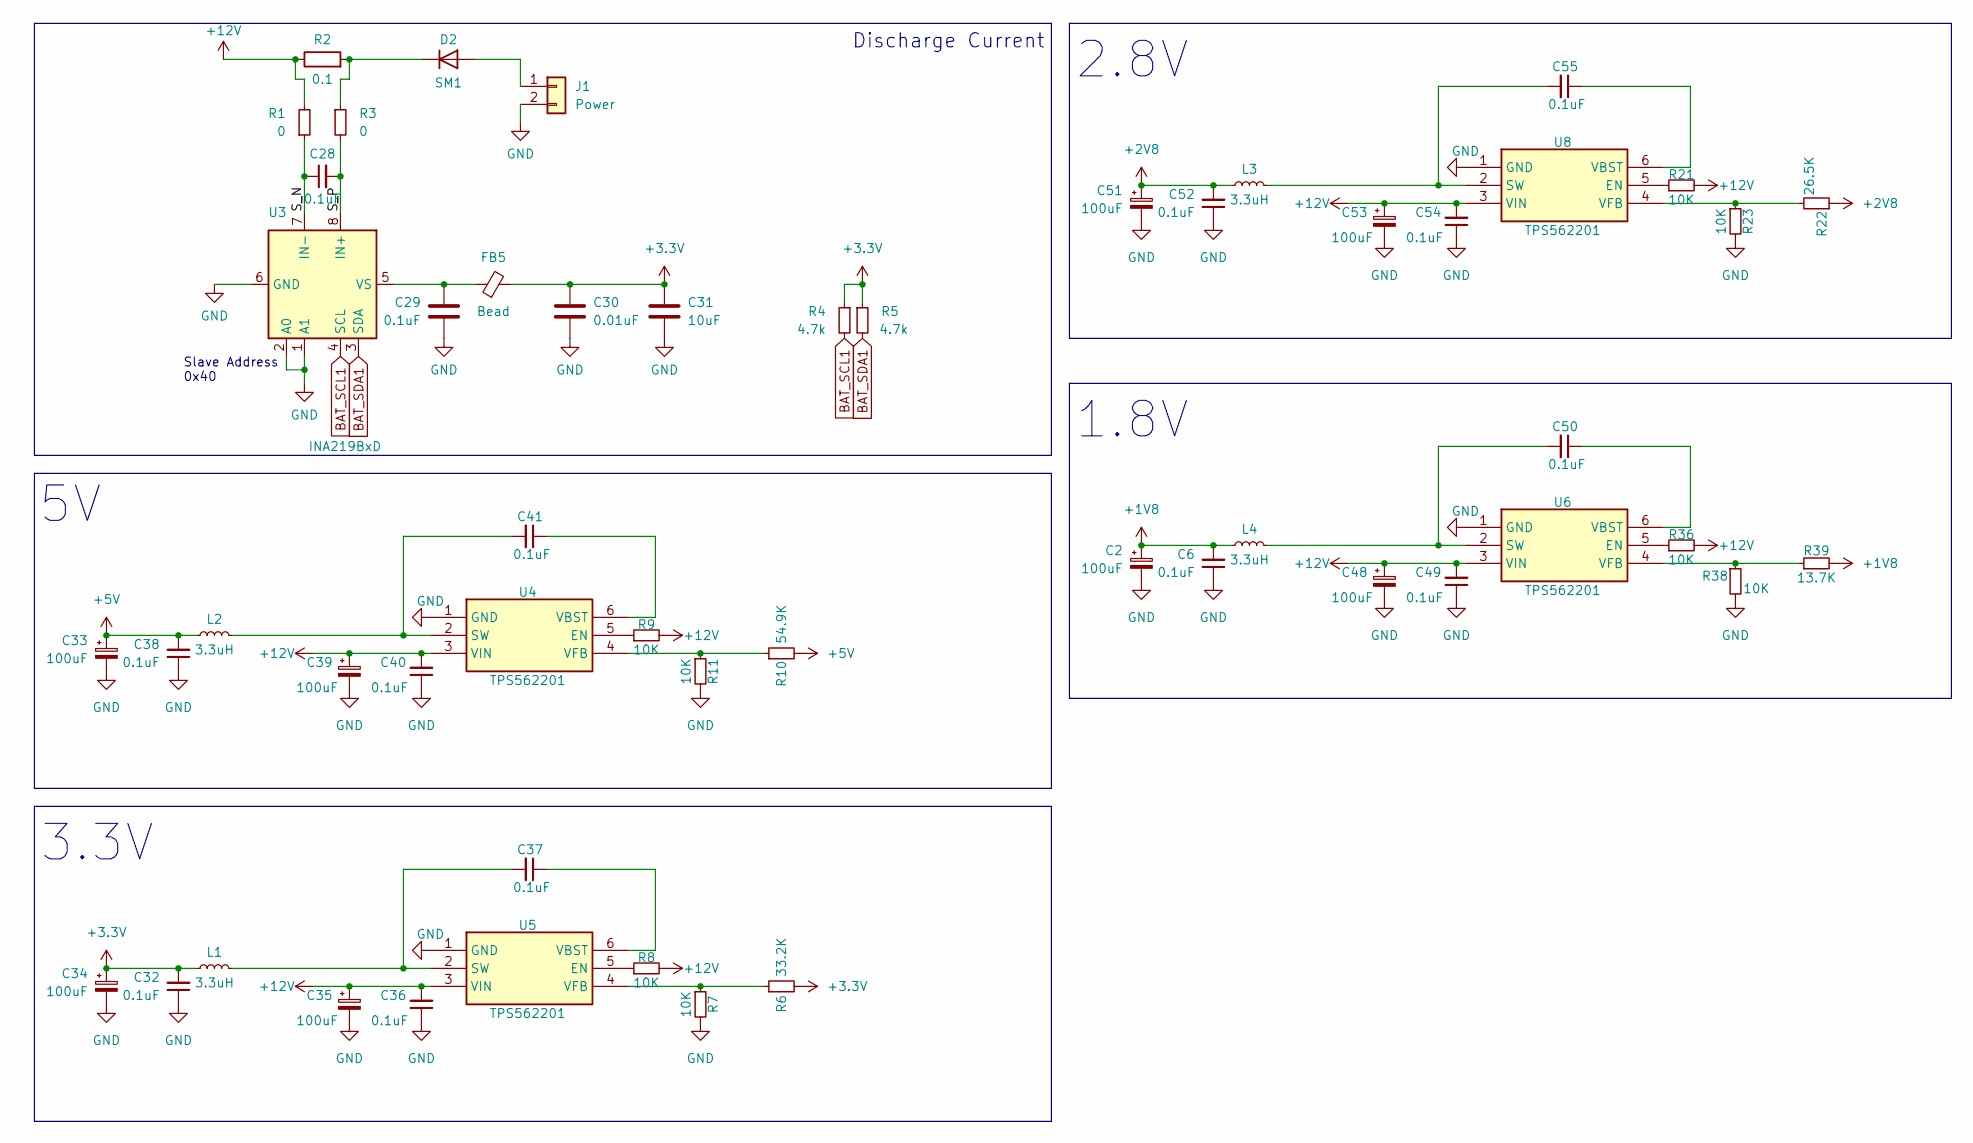
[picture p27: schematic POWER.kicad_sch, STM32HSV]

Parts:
C2, C33, C34, C35, C39, C48, C51, C53: 100uF; CP_Elec_6.3x5.9
C6, C28, C29, C32, C36, C37, C38, C40, C41, C49, C50, C52, C54, C55: 0.1uF; C_0603_1608Metric
C30: 0.01uF; C_0603_1608Metric
C31: 10uF; C_1206_3216Metric
D2: SM1; D_SMA
FB5: Bead; L_0805_2012Metric
J1: Power; PinHeader_1x02_P2.54mm_Vertical
L1, L2, L3, L4: 3.3uH; L_0805_2012Metric
R1, R3: 0; R_0603_1608Metric
R2: 0.1; R_2816_7142Metric
R4, R5: 4.7k; R_0603_1608Metric
R6: 33.2K; R_0603_1608Metric
R7, R8, R9, R11, R21, R23, R36, R38: 10K; R_0603_1608Metric
R10: 54.9K; R_0603_1608Metric
R22: 26.5K; R_0603_1608Metric
R39: 13.7K; R_0603_1608Metric
U3: INA219BxD; SOIC-8_3.9x4.9mm_P1.27mm
U4, U5, U6, U8: TPS562201; SOT-23-6; Mouser Part Number 595-TPS562201DDCR

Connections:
+1V8: C2.1, C6.2, L4.1, R39.2; also elsewhere on the board
+2V8: C51.1, C52.2, L3.1, R22.1; also elsewhere on the board
+3.3V: C30.1, C31.1, C32.2, C34.1, FB5.2, L1.1, R4.1, R5.1, R6.2; also elsewhere on the board
+5V: C33.1, C38.2, L2.2, R10.2; also elsewhere on the board
+12V: C35.1, C36.2, C39.1, C40.2, C48.1, C49.2, C53.1, C54.2, R1.2, R2.1, R8.2, R9.2, R21.2, R36.2, U4.3 (VIN), U5.3 (VIN), U6.3 (VIN), U8.3 (VIN); also elsewhere on the board
/POWER/S_N: C28.1, R1.1, U3.7 (IN-)
/POWER/S_P: C28.2, R3.2, U3.8 (IN+)
BAT_SCL1: R4.2, U3.4 (SCL); also elsewhere on the board
BAT_SDA1: R5.2, U3.3 (SDA); also elsewhere on the board
GND: C2.2, C6.1, C29.2, C30.2, C31.2, C32.1, C33.2, C34.2, C35.2, C36.1, C38.1, C39.2, C40.1, C48.2, C49.1, C51.2, C52.1, C53.2, C54.1, J1.2, R7.2, R11.2, R23.2, R38.2, U3.1 (A1), U3.2 (A0), U3.6 (GND), U4.1 (GND), U5.1 (GND), U6.1 (GND), U8.1 (GND); also elsewhere on the board
unnamed: D2.2 (A), J1.1
unnamed: D2.1 (K), R2.2, R3.1
unnamed: C29.1, FB5.1, U3.5 (VS)
unnamed: R9.1, U4.5 (EN)
unnamed: C41.2, L2.1, U4.2 (SW)
unnamed: C41.1, U4.6 (VBST)
unnamed: R10.1, R11.1, U4.4 (VFB)
unnamed: R8.1, U5.5 (EN)
unnamed: C37.2, L1.2, U5.2 (SW)
unnamed: C37.1, U5.6 (VBST)
unnamed: R6.1, R7.1, U5.4 (VFB)
unnamed: R36.1, U6.5 (EN)
unnamed: C50.2, L4.2, U6.2 (SW)
unnamed: C50.1, U6.6 (VBST)
unnamed: R38.1, R39.1, U6.4 (VFB)
unnamed: R21.1, U8.5 (EN)
unnamed: C55.2, L3.2, U8.2 (SW)
unnamed: C55.1, U8.6 (VBST)
unnamed: R22.2, R23.1, U8.4 (VFB)

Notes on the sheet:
Slave Address 0x40
1.8V
3.3V
2.8V
Discharge Current

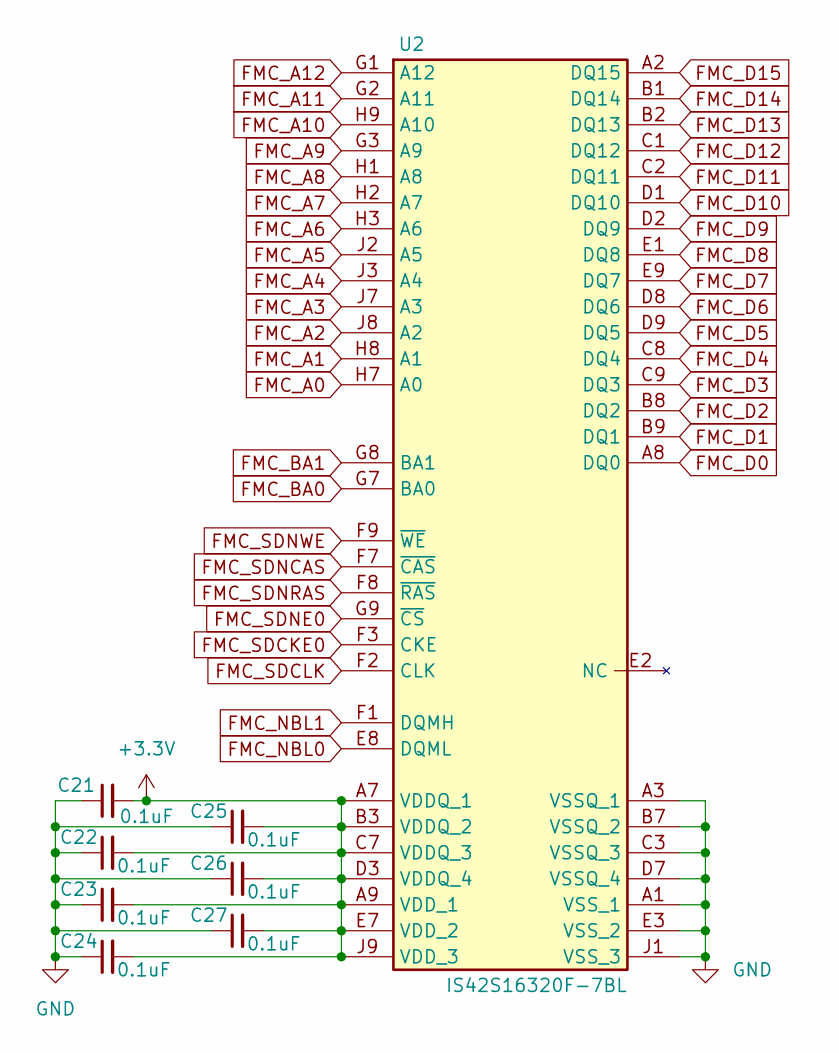
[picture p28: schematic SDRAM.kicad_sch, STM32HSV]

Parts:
C21, C22, C23, C24, C25, C26, C27: 0.1uF; C_0603_1608Metric
U2: IS42S16320F-7BL; IS42S16320F-7BLI; Mouser Part Number 870-42S16320F7BLI

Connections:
+3.3V: C21.2, C22.2, C23.2, C24.2, C25.2, C26.2, C27.2, U2.A7 (VDDQ_1), U2.A9 (VDD_1), U2.B3 (VDDQ_2), U2.C7 (VDDQ_3), U2.D3 (VDDQ_4), U2.E7 (VDD_2), U2.J9 (VDD_3); also elsewhere on the board
FMC_A0: U2.H7 (A0); also elsewhere on the board
FMC_A1: U2.H8 (A1); also elsewhere on the board
FMC_A2: U2.J8 (A2); also elsewhere on the board
FMC_A3: U2.J7 (A3); also elsewhere on the board
FMC_A4: U2.J3 (A4); also elsewhere on the board
FMC_A5: U2.J2 (A5); also elsewhere on the board
FMC_A6: U2.H3 (A6); also elsewhere on the board
FMC_A7: U2.H2 (A7); also elsewhere on the board
FMC_A8: U2.H1 (A8); also elsewhere on the board
FMC_A9: U2.G3 (A9); also elsewhere on the board
FMC_A10: U2.H9 (A10); also elsewhere on the board
FMC_A11: U2.G2 (A11); also elsewhere on the board
FMC_A12: U2.G1 (A12); also elsewhere on the board
FMC_BA0: U2.G7 (BA0); also elsewhere on the board
FMC_BA1: U2.G8 (BA1); also elsewhere on the board
FMC_D0: U2.A8 (DQ0); also elsewhere on the board
FMC_D1: U2.B9 (DQ1); also elsewhere on the board
FMC_D2: U2.B8 (DQ2); also elsewhere on the board
FMC_D3: U2.C9 (DQ3); also elsewhere on the board
FMC_D4: U2.C8 (DQ4); also elsewhere on the board
FMC_D5: U2.D9 (DQ5); also elsewhere on the board
FMC_D6: U2.D8 (DQ6); also elsewhere on the board
FMC_D7: U2.E9 (DQ7); also elsewhere on the board
FMC_D8: U2.E1 (DQ8); also elsewhere on the board
FMC_D9: U2.D2 (DQ9); also elsewhere on the board
FMC_D10: U2.D1 (DQ10); also elsewhere on the board
FMC_D11: U2.C2 (DQ11); also elsewhere on the board
FMC_D12: U2.C1 (DQ12); also elsewhere on the board
FMC_D13: U2.B2 (DQ13); also elsewhere on the board
FMC_D14: U2.B1 (DQ14); also elsewhere on the board
FMC_D15: U2.A2 (DQ15); also elsewhere on the board
FMC_NBL0: U2.E8 (DQML); also elsewhere on the board
FMC_NBL1: U2.F1 (DQMH); also elsewhere on the board
FMC_SDCKE0: U2.F3 (CKE); also elsewhere on the board
FMC_SDCLK: U2.F2 (CLK); also elsewhere on the board
FMC_SDNCAS: U2.F7 (~CAS); also elsewhere on the board
FMC_SDNE0: U2.G9 (~CS); also elsewhere on the board
FMC_SDNRAS: U2.F8 (~RAS); also elsewhere on the board
FMC_SDNWE: U2.F9 (~WE); also elsewhere on the board
GND: C21.1, C22.1, C23.1, C24.1, C25.1, C26.1, C27.1, U2.A1 (VSS_1), U2.A3 (VSSQ_1), U2.B7 (VSSQ_2), U2.C3 (VSSQ_3), U2.D7 (VSSQ_4), U2.E3 (VSS_2), U2.J1 (VSS_3); also elsewhere on the board

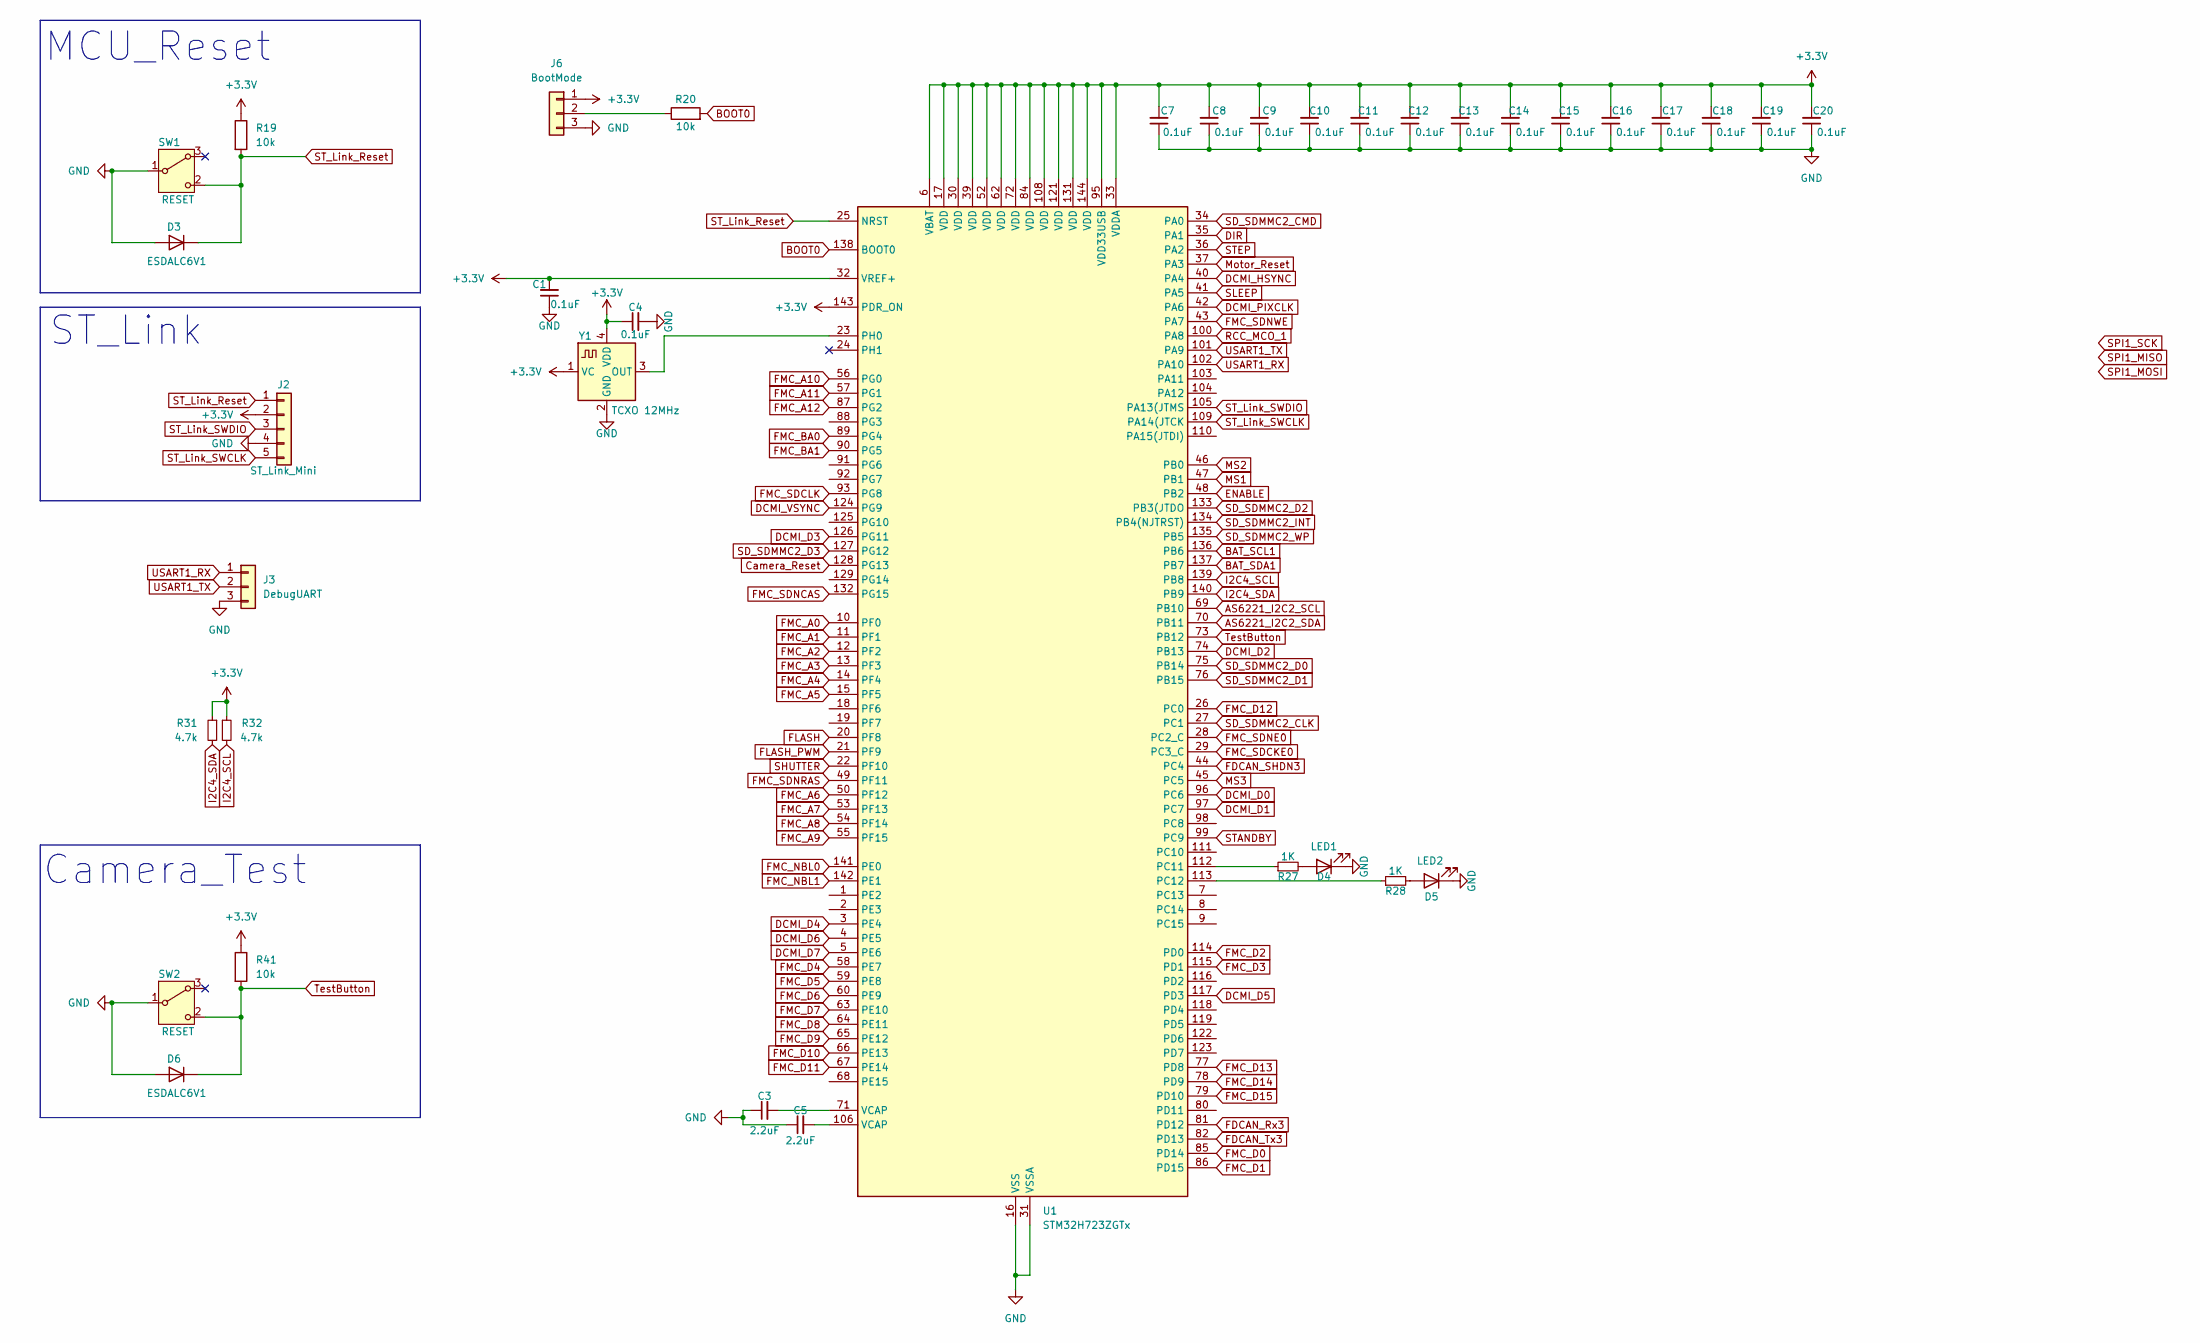
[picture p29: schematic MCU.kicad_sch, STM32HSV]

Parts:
C1, C4, C7, C8, C9, C10, C11, C12, C13, C14, C15, C16, C17, C18, C19, C20: 0.1uF; C_0603_1608Metric
C3, C5: 2.2uF; C_0805_2012Metric
D3, D6: ESDALC6V1; D_SOD-882D
D4: LED1; LED_0805_2012Metric
D5: LED2; LED_0805_2012Metric
J2: ST_Link_Mini; PinHeader_1x05_P2.54mm_Vertical
J3: DebugUART; PinHeader_1x03_P2.54mm_Vertical
J6: BootMode; PinHeader_1x03_P2.54mm_Vertical
R19, R20, R41: 10k; R_0603_1608Metric
R27, R28: 1K; R_0603_1608Metric
R31, R32: 4.7k; R_0603_1608Metric
SW1, SW2: RESET; TLSMDT3C020GLFS
U1: STM32H723ZGTx; LQFP-144_20x20mm_P0.5mm
Y1: TCXO 12MHz; Oscillator_SMD_Fox_FT5H_5.0x3.2mm

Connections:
+3.3V: C1.2, C4.1, C7.2, C8.2, C9.2, C10.2, C11.2, C12.2, C13.2, C14.2, C15.2, C16.2, C17.2, C18.2, C19.2, C20.2, J2.2, J6.1, R19.1, R31.1, R32.1, R41.1, U1.6 (VBAT), U1.17 (VDD), U1.30 (VDD), U1.32 (VREF+), U1.33 (VDDA), U1.39 (VDD), U1.52 (VDD), U1.62 (VDD), U1.72 (VDD), U1.84 (VDD), U1.95 (VDD33USB), U1.108 (VDD), U1.121 (VDD), U1.131 (VDD), U1.143 (PDR_ON), U1.144 (VDD), Y1.1 (VC), Y1.4 (VDD); also elsewhere on the board
AS6221_I2C2_SCL: U1.69 (PB10); also elsewhere on the board
AS6221_I2C2_SDA: U1.70 (PB11); also elsewhere on the board
BAT_SCL1: U1.136 (PB6); also elsewhere on the board
BAT_SDA1: U1.137 (PB7); also elsewhere on the board
BOOT0: R20.2, U1.138 (BOOT0)
Camera_Reset: U1.128 (PG13); also elsewhere on the board
DCMI_D0: U1.96 (PC6); also elsewhere on the board
DCMI_D1: U1.97 (PC7); also elsewhere on the board
DCMI_D2: U1.74 (PB13); also elsewhere on the board
DCMI_D3: U1.126 (PG11); also elsewhere on the board
DCMI_D4: U1.3 (PE4); also elsewhere on the board
DCMI_D5: U1.117 (PD3); also elsewhere on the board
DCMI_D6: U1.4 (PE5); also elsewhere on the board
DCMI_D7: U1.5 (PE6); also elsewhere on the board
DCMI_HSYNC: U1.40 (PA4); also elsewhere on the board
DCMI_PIXCLK: U1.42 (PA6); also elsewhere on the board
DCMI_VSYNC: U1.124 (PG9); also elsewhere on the board
DIR: U1.35 (PA1); also elsewhere on the board
ENABLE: U1.48 (PB2); also elsewhere on the board
FDCAN_Rx3: U1.81 (PD12); also elsewhere on the board
FDCAN_SHDN3: U1.44 (PC4); also elsewhere on the board
FDCAN_Tx3: U1.82 (PD13); also elsewhere on the board
FLASH: U1.20 (PF8); also elsewhere on the board
FLASH_PWM: U1.21 (PF9); also elsewhere on the board
FMC_A0: U1.10 (PF0); also elsewhere on the board
FMC_A1: U1.11 (PF1); also elsewhere on the board
FMC_A2: U1.12 (PF2); also elsewhere on the board
FMC_A3: U1.13 (PF3); also elsewhere on the board
FMC_A4: U1.14 (PF4); also elsewhere on the board
FMC_A5: U1.15 (PF5); also elsewhere on the board
FMC_A6: U1.50 (PF12); also elsewhere on the board
FMC_A7: U1.53 (PF13); also elsewhere on the board
FMC_A8: U1.54 (PF14); also elsewhere on the board
FMC_A9: U1.55 (PF15); also elsewhere on the board
FMC_A10: U1.56 (PG0); also elsewhere on the board
FMC_A11: U1.57 (PG1); also elsewhere on the board
FMC_A12: U1.87 (PG2); also elsewhere on the board
FMC_BA0: U1.89 (PG4); also elsewhere on the board
FMC_BA1: U1.90 (PG5); also elsewhere on the board
FMC_D0: U1.85 (PD14); also elsewhere on the board
FMC_D1: U1.86 (PD15); also elsewhere on the board
FMC_D2: U1.114 (PD0); also elsewhere on the board
FMC_D3: U1.115 (PD1); also elsewhere on the board
FMC_D4: U1.58 (PE7); also elsewhere on the board
FMC_D5: U1.59 (PE8); also elsewhere on the board
FMC_D6: U1.60 (PE9); also elsewhere on the board
FMC_D7: U1.63 (PE10); also elsewhere on the board
FMC_D8: U1.64 (PE11); also elsewhere on the board
FMC_D9: U1.65 (PE12); also elsewhere on the board
FMC_D10: U1.66 (PE13); also elsewhere on the board
FMC_D11: U1.67 (PE14); also elsewhere on the board
FMC_D12: U1.26 (PC0); also elsewhere on the board
FMC_D13: U1.77 (PD8); also elsewhere on the board
FMC_D14: U1.78 (PD9); also elsewhere on the board
FMC_D15: U1.79 (PD10); also elsewhere on the board
FMC_NBL0: U1.141 (PE0); also elsewhere on the board
FMC_NBL1: U1.142 (PE1); also elsewhere on the board
FMC_SDCKE0: U1.29 (PC3_C); also elsewhere on the board
FMC_SDCLK: U1.93 (PG8); also elsewhere on the board
FMC_SDNCAS: U1.132 (PG15); also elsewhere on the board
FMC_SDNE0: U1.28 (PC2_C); also elsewhere on the board
FMC_SDNRAS: U1.49 (PF11); also elsewhere on the board
FMC_SDNWE: U1.43 (PA7); also elsewhere on the board
GND: C1.1, C3.1, C4.2, C5.1, C7.1, C8.1, C9.1, C10.1, C11.1, C12.1, C13.1, C14.1, C15.1, C16.1, C17.1, C18.1, C19.1, C20.1, D3.2 (A), D4.1 (K), D5.1 (K), D6.2 (A), J2.4, J3.3, J6.3, SW1.1 (B), SW2.1 (B), U1.16 (VSS), U1.31 (VSSA), U1.38 (VSS), U1.51 (VSS), U1.61 (VSS), U1.83 (VSS), U1.94 (VSS), U1.107 (VSS), U1.120 (VSS), U1.130 (VSS), Y1.2 (GND); also elsewhere on the board
I2C4_SCL: R32.2, U1.139 (PB8); also elsewhere on the board
I2C4_SDA: R31.2, U1.140 (PB9); also elsewhere on the board
MS1: U1.47 (PB1); also elsewhere on the board
MS2: U1.46 (PB0); also elsewhere on the board
MS3: U1.45 (PC5); also elsewhere on the board
Motor_Reset: U1.37 (PA3); also elsewhere on the board
unnamed: C3.2, U1.71 (VCAP)
unnamed: C5.2, U1.106 (VCAP)
unnamed: D4.2 (A), R27.2
unnamed: D5.2 (A), R28.2
unnamed: J6.2, R20.1
unnamed: R27.1, U1.112 (PC11)
unnamed: R28.1, U1.113 (PC12)
unnamed: U1.23 (PH0), Y1.3 (OUT)
RCC_MCO_1: U1.100 (PA8); also elsewhere on the board
SD_SDMMC2_CLK: U1.27 (PC1); also elsewhere on the board
SD_SDMMC2_CMD: U1.34 (PA0); also elsewhere on the board
SD_SDMMC2_D0: U1.75 (PB14); also elsewhere on the board
SD_SDMMC2_D1: U1.76 (PB15); also elsewhere on the board
SD_SDMMC2_D2: U1.133 (PB3(JTDO); also elsewhere on the board
SD_SDMMC2_D3: U1.127 (PG12); also elsewhere on the board
SD_SDMMC2_INT: U1.134 (PB4(NJTRST)); also elsewhere on the board
SD_SDMMC2_WP: U1.135 (PB5)
SHUTTER: U1.22 (PF10); also elsewhere on the board
SLEEP: U1.41 (PA5)
STANDBY: U1.99 (PC9)
STEP: U1.36 (PA2); also elsewhere on the board
ST_Link_Reset: D3.1 (K), J2.1, R19.2, SW1.2 (C), U1.25 (NRST)
ST_Link_SWCLK: J2.5, U1.109 (PA14(JTCK)
ST_Link_SWDIO: J2.3, U1.105 (PA13(JTMS)
TestButton: D6.1 (K), R41.2, SW2.2 (C), U1.73 (PB12)
USART1_RX: J3.1, U1.102 (PA10)
USART1_TX: J3.2, U1.101 (PA9)

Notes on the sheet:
Camera_Test
ST_Link
MCU_Reset

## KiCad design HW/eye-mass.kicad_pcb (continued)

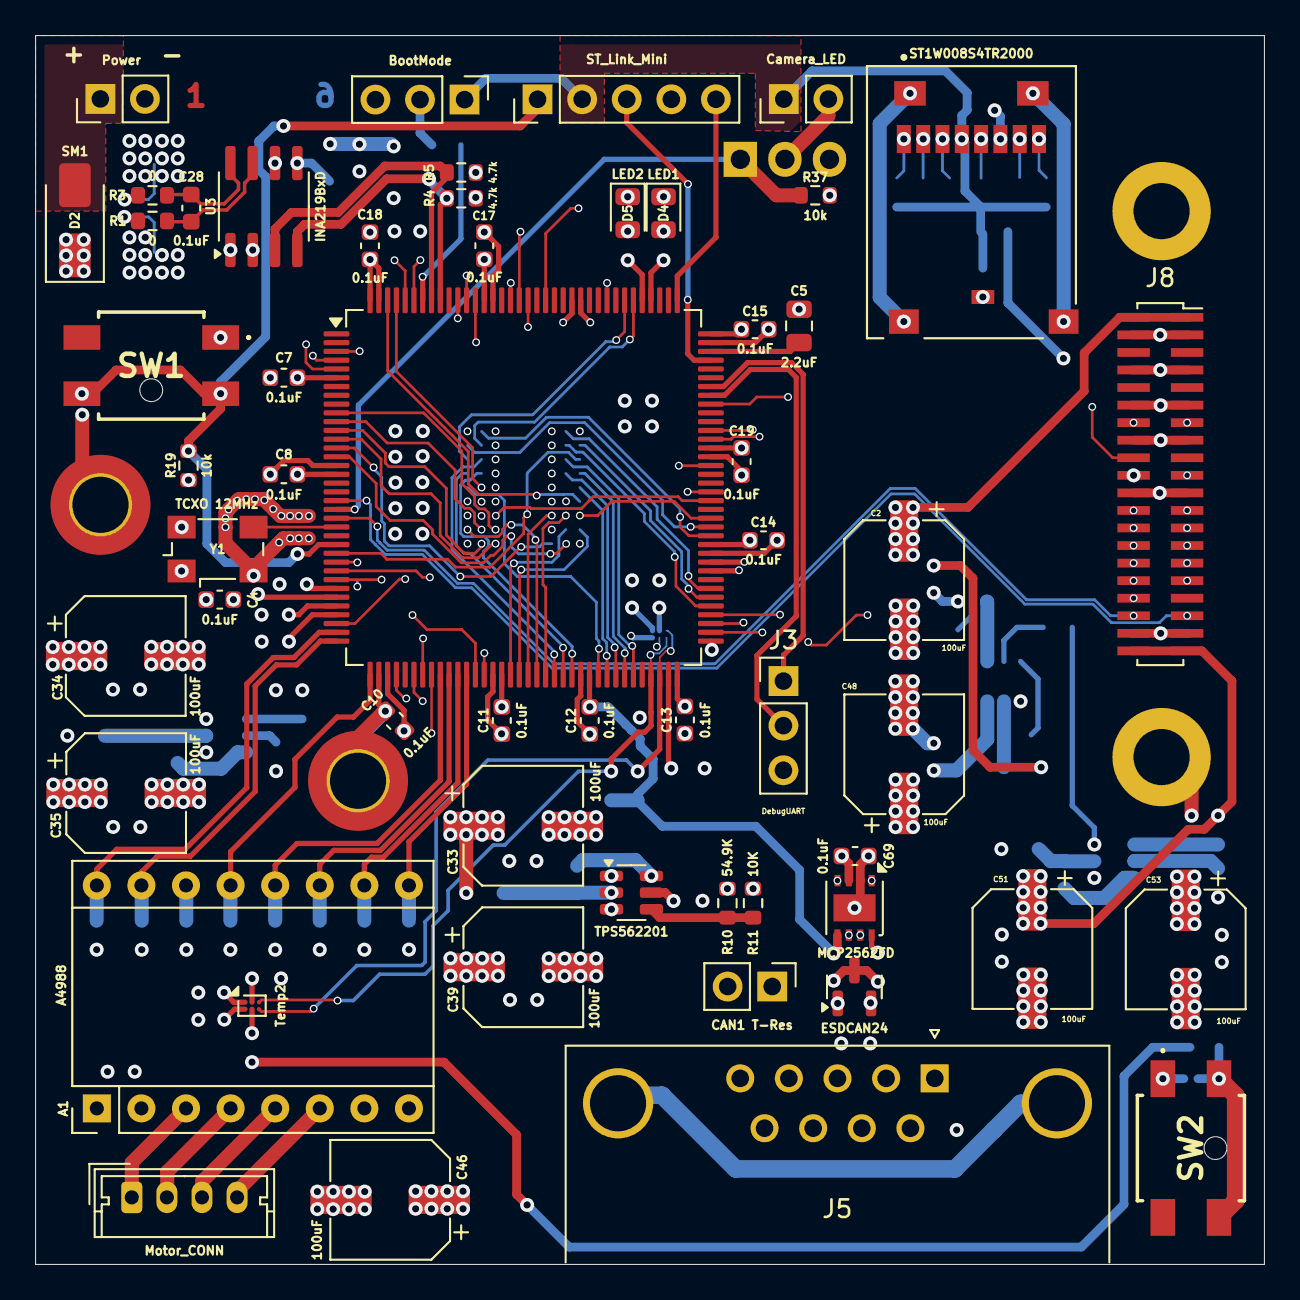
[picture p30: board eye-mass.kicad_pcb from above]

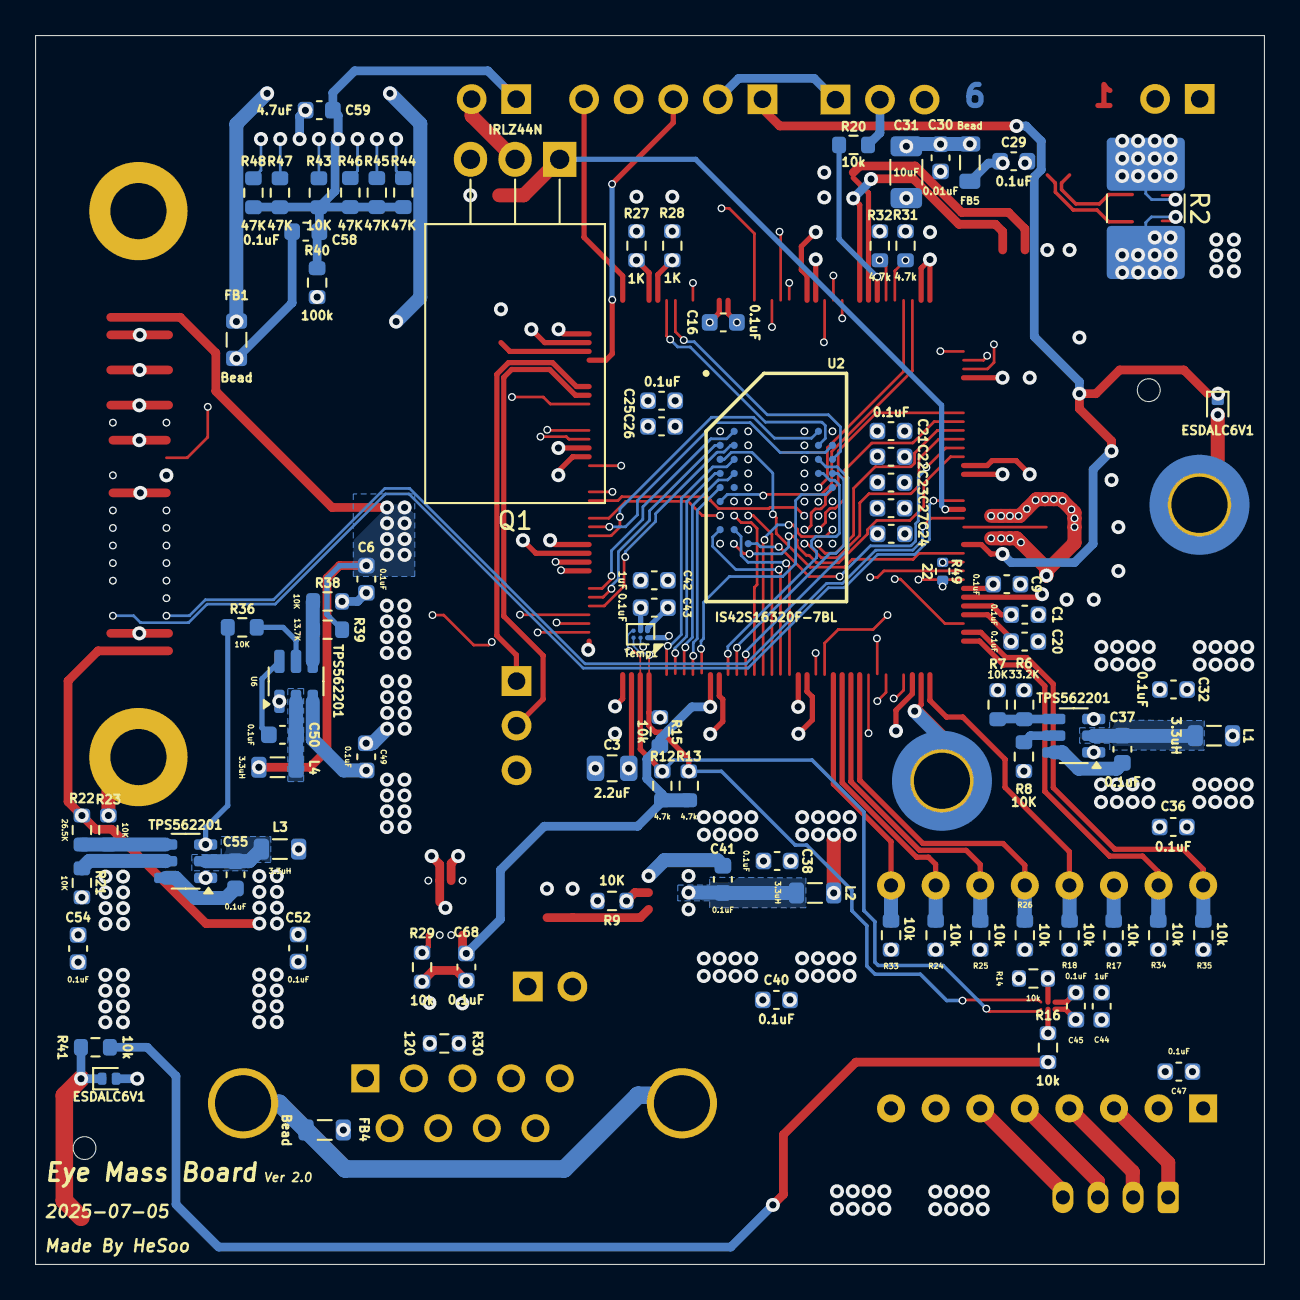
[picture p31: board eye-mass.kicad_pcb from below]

Board: 6 copper layers, 70.0 x 70.0 mm, 147 parts (90 on the bottom side), 135 nets.

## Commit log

2025-08-21 Eye-mass Hardware v2.0
    [Camera.kicad_sch, FDCAN.kicad_sch, LOAD_CELL.kicad_sch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]
2025-08-22 file update
    [eye_mass_3.kicad_pcb, eye_mass_3.kicad_sch]
